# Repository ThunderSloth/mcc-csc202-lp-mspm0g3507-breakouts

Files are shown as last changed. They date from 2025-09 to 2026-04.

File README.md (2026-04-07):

# MCC CSC202 — LP-MSPM0G3507 Breakout Boards

KiCad project files and fabrication outputs for **breakout boards based on the TI MSPM0G3507 LaunchPad footprint** designed to fit dual- and triple-breadboard platforms (e.g., Jameco ValuePro) for use in Monroe Community College’s CSC-202 course.

---

## ℹ️  Hardware Documentation (MkDocs)

- **[Live Docs Site (renders + PDFs + iBOM + fabrication zips](https://thundersloth.github.io/mcc-csc202-lp-mspm0g3507-breakouts/)**  

---

## 📁 Boards

### **2-Term Breakout**
- [Docs Page](https://thundersloth.github.io/mcc-csc202-lp-mspm0g3507-breakouts/2-term/)
- [Download Gerbers (ZIP)](https://thundersloth.github.io/mcc-csc202-lp-mspm0g3507-breakouts/artifacts/2-term/fab/CSC202_LP_MSPM0G3507_2TERM_BREAKOUT_fab.zip)

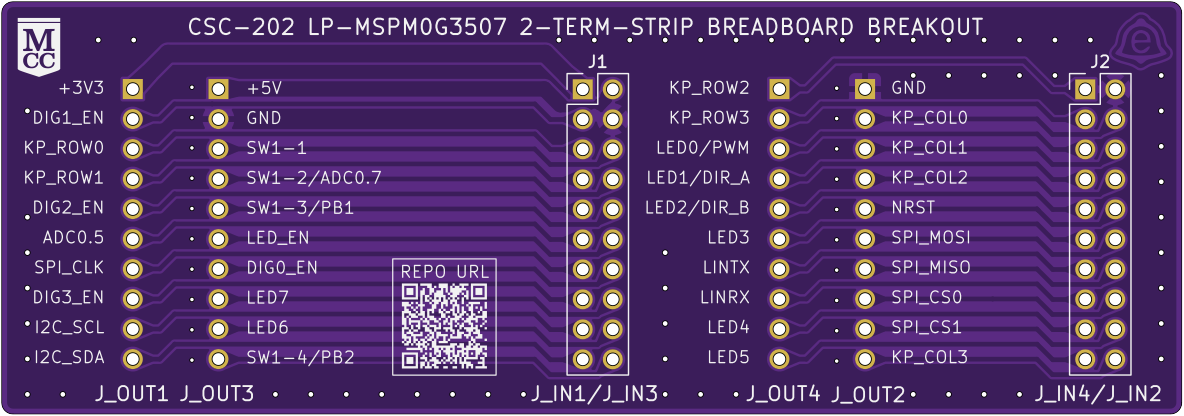
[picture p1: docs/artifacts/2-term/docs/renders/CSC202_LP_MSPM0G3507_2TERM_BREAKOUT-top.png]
2-Term Top Render


---

### **3-Term Breakout**
- [Docs Page](https://thundersloth.github.io/mcc-csc202-lp-mspm0g3507-breakouts/3-term/)
- [Download Gerbers (ZIP)](https://thundersloth.github.io/mcc-csc202-lp-mspm0g3507-breakouts/artifacts/3-term/fab/CSC202_LP_MSPM0G3507_3TERM_BREAKOUT_fab.zip)

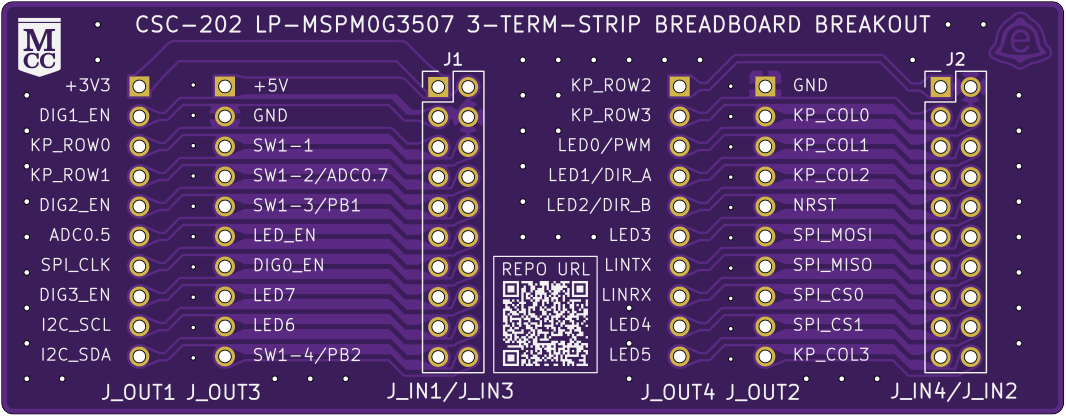
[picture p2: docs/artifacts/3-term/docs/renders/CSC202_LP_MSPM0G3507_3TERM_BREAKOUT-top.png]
3-Term Top Render


---

### **LED Display Module**
The CSC-202 LED Module is a visual output board featuring an 8-LED bar graph and a 4-digit seven-segment display. The LEDs and display segments can be driven either directly via GPIO (current sinking) or through an SPI shift register interface. A jumper shunt selects the control mode, allowing the module to demonstrate both parallel GPIO control and serial output expansion. The board is designed to plug directly into a standard breadboard for easy prototyping and lab use.
- [Docs Page](https://thundersloth.github.io/mcc-csc202-lp-mspm0g3507-breakouts/led-module/)
- [Download Gerbers (ZIP)](https://thundersloth.github.io/mcc-csc202-lp-mspm0g3507-breakouts/artifacts/led-module/fab/CSC202_LED_MODULE_fab.zip.zip)

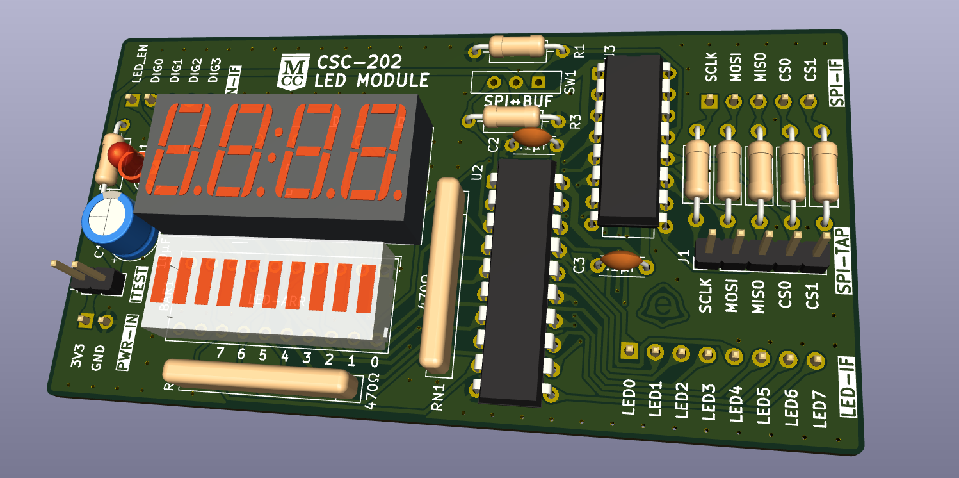
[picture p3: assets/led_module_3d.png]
LED Display Module 3D Render


---

### **DIP Switch / Pushbutton Module**
The CSC-202 DIP Switch / Pushbutton Module provides four digital input channels, each connected to both a DIP switch and a momentary pushbutton. This allows testing of both persistent and transient inputs on shared GPIO lines. An additional analog input is provided via an onboard potentiometer, which can be enabled or disconnected using a dedicated DIP switch. The module is designed for direct breadboard use and serves as a simple, reusable input interface for labs and debugging.

- [Docs Page](https://thundersloth.github.io/mcc-csc202-lp-mspm0g3507-breakouts/dipsw-module/)
- [Download Gerbers (ZIP)](https://thundersloth.github.io/mcc-csc202-lp-mspm0g3507-breakouts/artifacts/dipsw-module/fab/CSC202_DIPSW_fab.zip)

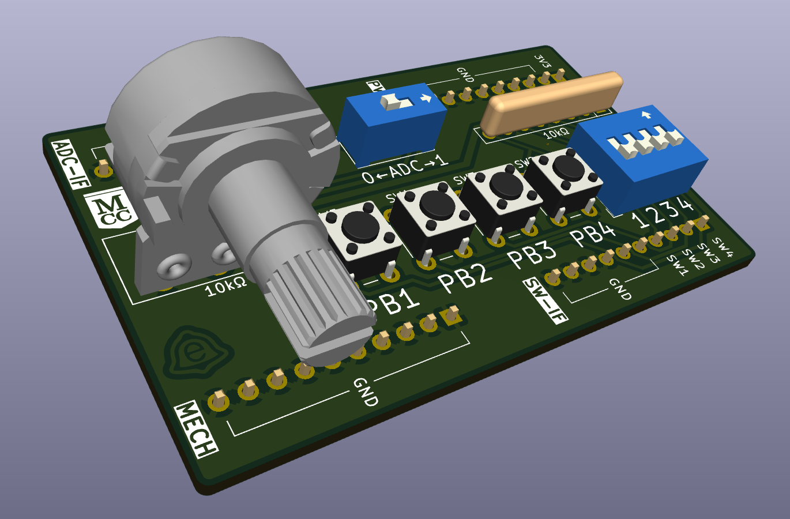
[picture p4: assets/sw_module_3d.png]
DIP Switch Module 3D Render


---

## 🛠 Repo Layout

- `hardware/pcb/kicad/` → KiCad source projects (per-board)
- `hardware/kibot/` → KiBot config
- `outputs/` → local generated artifacts (ignored/regen as needed)
- `docs/` + `docs/artifacts/` → MkDocs site + published artifacts

---

## 🔄 Generating outputs locally

If you want to regenerate all artifacts with KiBot + sync them into MkDocs:

```bash
make
```

---

## 📸 Fabricated Board Photos

<p align="center">
    <strong>3-Term Breakout</strong><br>
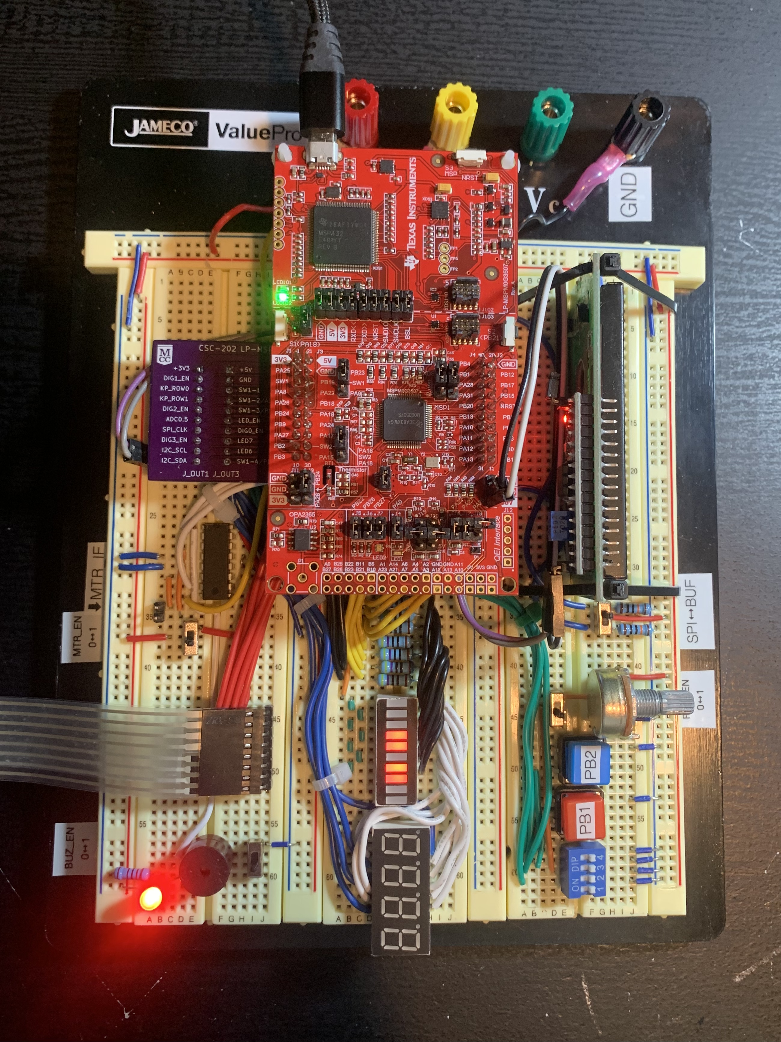
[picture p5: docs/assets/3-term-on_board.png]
3-Term breakout on breadboard
  
</p>

<p align="center">
  <strong>LED Display Module</strong><br>
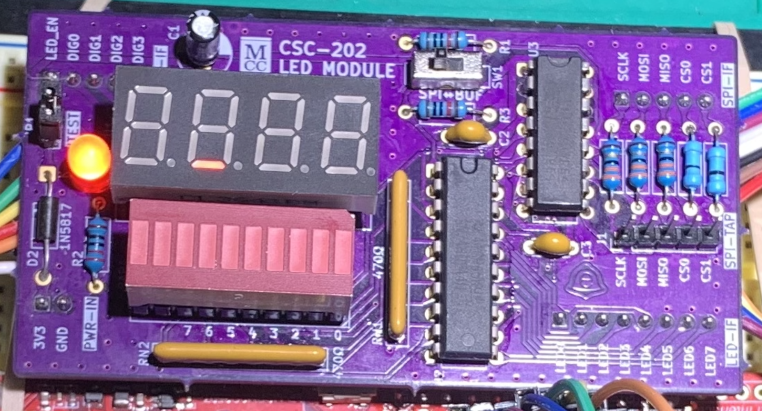
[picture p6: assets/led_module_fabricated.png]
Fabricated LED Module
  
</p>

---

## 📐 Example Breadboard Application

The diagram below shows an example application implemented on a 3-terminal breadboard.

<p align="center">
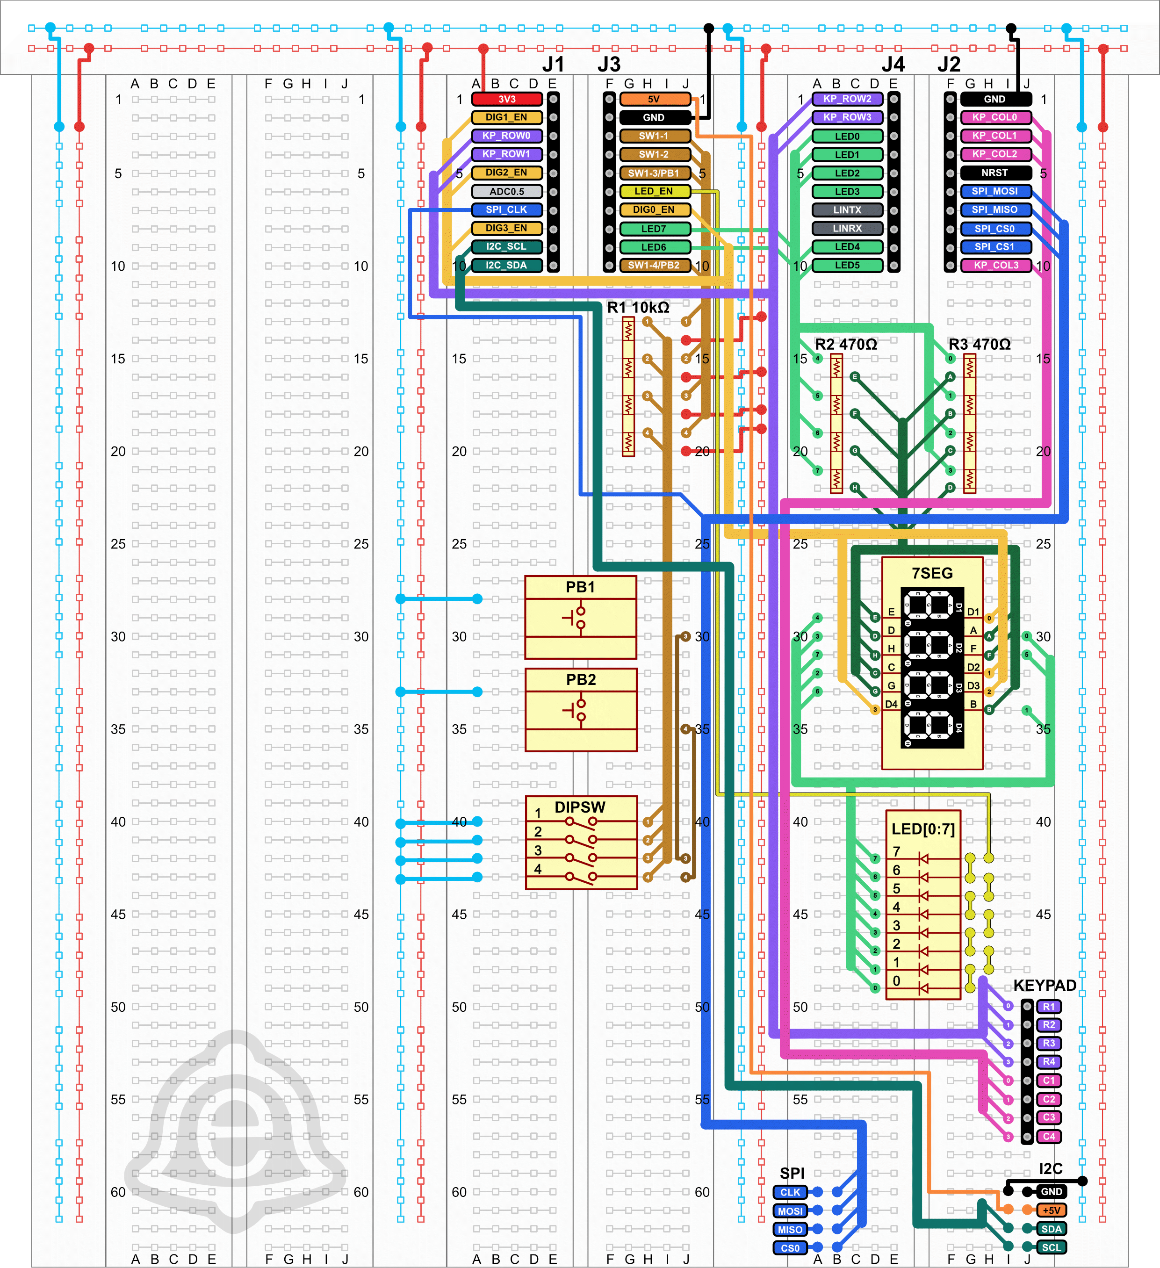
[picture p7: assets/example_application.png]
Example Application Breadboard Schematic
  
</p>

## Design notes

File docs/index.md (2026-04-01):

# CSC-202 LP-MSPM0G3507 Breakouts — Hardware Documentation

This site hosts the complete set of design, assembly, and fabrication artifacts generated from the KiCad projects via **KiBot**.

---

## ℹ️ Project
GitHub Repository: [ThunderSloth/mcc-csc202-lp-mspm0g3507-breakouts](https://github.com/ThunderSloth/mcc-csc202-lp-mspm0g3507-breakouts)

---

## 📁 Boards
### 2-Term Breakout

2-Term Breakout top render

➡️ [Open page](2-term.md)

---

### 3-Term Breakout

3-Term Breakout top render

➡️ [Open page](3-term.md)

---

### LED Display Module

<div class="img-row">
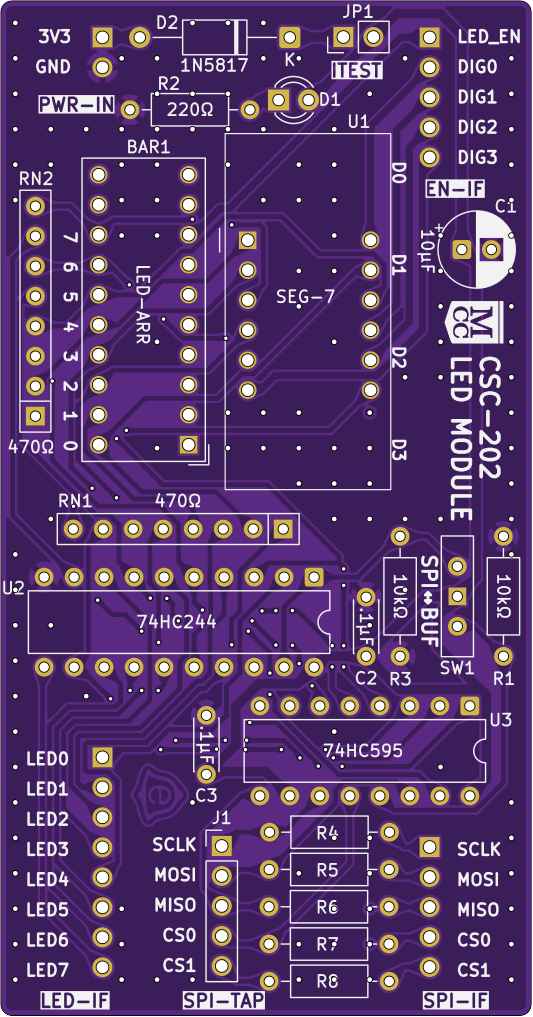
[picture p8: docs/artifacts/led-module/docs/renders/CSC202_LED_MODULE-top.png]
LED Display Module top render
    
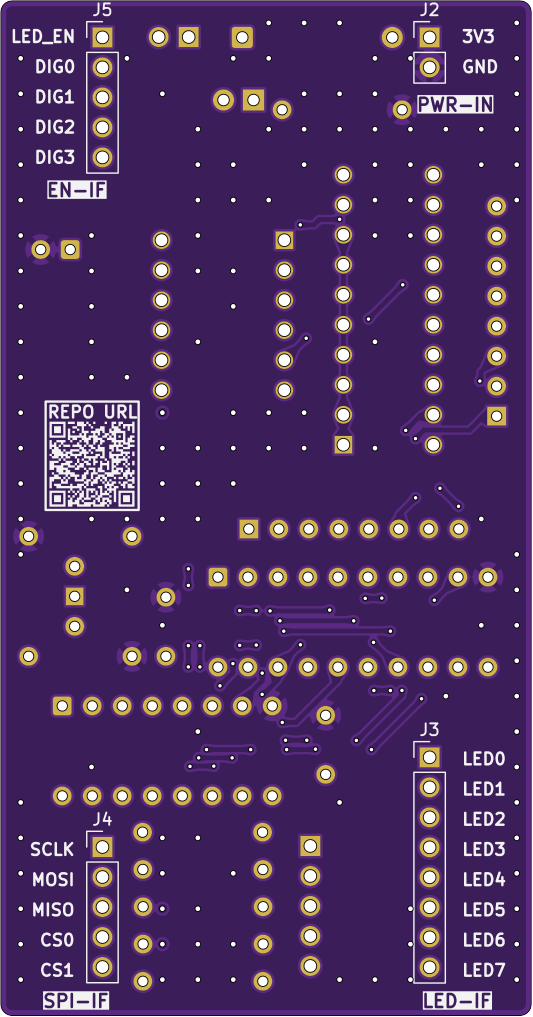
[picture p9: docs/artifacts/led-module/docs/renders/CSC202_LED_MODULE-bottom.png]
LED Display Module bottom render
    
</div>

➡️ [Open page](led-module.md)

---

### DIP Switch Module

<div class="img-row">
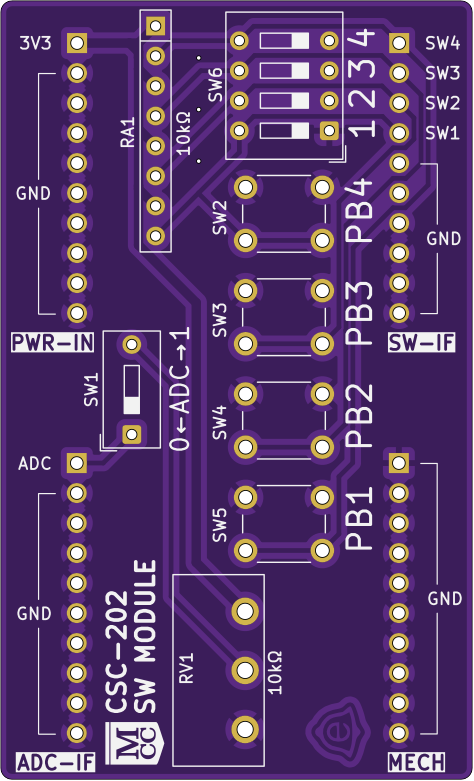
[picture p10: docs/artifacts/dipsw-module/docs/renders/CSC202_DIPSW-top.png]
DIP Switch Module top render
    
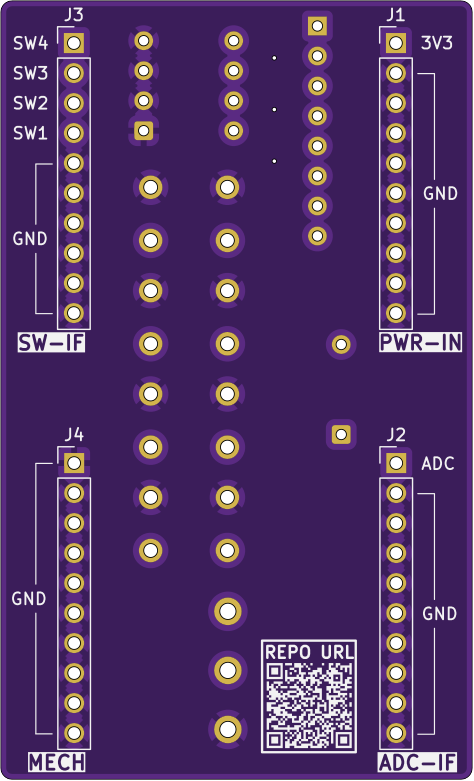
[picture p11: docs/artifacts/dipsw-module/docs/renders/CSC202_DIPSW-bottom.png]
DIP Switch Module bottom render
    
</div>

➡️ [Open page](dipsw-module.md)

---

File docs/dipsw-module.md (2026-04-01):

# DIP Switch Module

This page hosts the complete set of design, assembly, and fabrication artifacts generated from the KiCad project via **KiBot**.

---

## 📐 Design

- **Schematic (PDF)** [[view]](artifacts/dipsw-module/docs/schematic/CSC202_DIPSW-schematic.pdf)
- **PCB Render — Top (2D)** [[view]](artifacts/dipsw-module/docs/renders/CSC202_DIPSW-top.png)
- **PCB Render — Bottom (2D)** [[view]](artifacts/dipsw-module/docs/renders/CSC202_DIPSW-bottom.png)

---

## 🔧 Assembly

- **Interactive BOM (iBOM)** [[view]](artifacts/dipsw-module/docs/ibom/CSC202_DIPSW-ibom.html)
- **Bill of Materials (CSV)** [[view]](artifacts/dipsw-module/assembly/CSC202_DIPSW-bom.csv.html) [[download]](artifacts/dipsw-module/assembly/CSC202_DIPSW-bom.csv)
- **Assembly Drawing — Top (PDF)** [[view]](artifacts/dipsw-module/docs/assembly/CSC202_DIPSW-assembly-top.pdf)
- **Assembly Drawing — Bottom (PDF)** [[view]](artifacts/dipsw-module/docs/assembly/CSC202_DIPSW-assembly-bottom.pdf)

---

## ⚙️ Fabrication

- **Fabrication Drawing (PDF)** [[view]](artifacts/dipsw-module/docs/fab/CSC202_DIPSW-fab-drawing.pdf)
- **Gerbers & Drill Files (ZIP)** [[download]](artifacts/dipsw-module/fab/CSC202_DIPSW_fab.zip)

---

## 🧊 Mechanical

- **3D STEP Model** [[download]](artifacts/dipsw-module/mcad/CSC202_DIPSW-3D.step)

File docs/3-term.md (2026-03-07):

# 3-Term Breakout

This page hosts the complete set of design, assembly, and fabrication artifacts generated from the KiCad project via **KiBot**.

---

## 📐 Design

- **Schematic (PDF)** [[view]](artifacts/3-term/docs/schematic/CSC202_LP_MSPM0G3507_3TERM_BREAKOUT-schematic.pdf)
- **PCB Render — Top (2D)** [[view]](artifacts/3-term/docs/renders/CSC202_LP_MSPM0G3507_3TERM_BREAKOUT-top.png)
- **PCB Render — Bottom (2D)** [[view]](artifacts/3-term/docs/renders/CSC202_LP_MSPM0G3507_3TERM_BREAKOUT-bottom.png)

---

## 🔧 Assembly

- **Interactive BOM (iBOM)** [[view]](artifacts/3-term/docs/ibom/CSC202_LP_MSPM0G3507_3TERM_BREAKOUT-ibom.html)
- **Bill of Materials (CSV)** [[view]](artifacts/3-term/assembly/CSC202_LP_MSPM0G3507_3TERM_BREAKOUT-bom.csv.html) [[download]](artifacts/3-term/assembly/CSC202_LP_MSPM0G3507_3TERM_BREAKOUT-bom.csv)
- **Assembly Drawing — Top (PDF)** [[view]](artifacts/3-term/docs/assembly/CSC202_LP_MSPM0G3507_3TERM_BREAKOUT-assembly-top.pdf)
- **Assembly Drawing — Bottom (PDF)** [[view]](artifacts/3-term/docs/assembly/CSC202_LP_MSPM0G3507_3TERM_BREAKOUT-assembly-bottom.pdf)

---

## ⚙️ Fabrication

- **Fabrication Drawing (PDF)** [[view]](artifacts/3-term/docs/fab/CSC202_LP_MSPM0G3507_3TERM_BREAKOUT-fab-drawing.pdf)
- **Gerbers & Drill Files (ZIP)** [[download]](artifacts/3-term/fab/CSC202_LP_MSPM0G3507_3TERM_BREAKOUT_fab.zip)

---

## 🧊 Mechanical

- **3D STEP Model** [[download]](artifacts/3-term/mcad/CSC202_LP_MSPM0G3507_3TERM_BREAKOUT-3D.step)

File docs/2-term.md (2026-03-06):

# 2-Term Breakout

This page hosts the complete set of design, assembly, and fabrication artifacts generated from the KiCad project via **KiBot**.

---

## 📐 Design

- **Schematic (PDF)** [[view]](artifacts/2-term/docs/schematic/CSC202_LP_MSPM0G3507_2TERM_BREAKOUT-schematic.pdf)
- **PCB Render — Top (2D)** [[view]](artifacts/2-term/docs/renders/CSC202_LP_MSPM0G3507_2TERM_BREAKOUT-top.png)
- **PCB Render — Bottom (2D)** [[view]](artifacts/2-term/docs/renders/CSC202_LP_MSPM0G3507_2TERM_BREAKOUT-bottom.png)

---

## 🔧 Assembly

- **Interactive BOM (iBOM)** [[view]](artifacts/2-term/docs/ibom/CSC202_LP_MSPM0G3507_2TERM_BREAKOUT-ibom.html)
- **Bill of Materials (CSV)** [[view]](artifacts/2-term/assembly/CSC202_LP_MSPM0G3507_2TERM_BREAKOUT-bom.csv.html) [[download]](artifacts/2-term/assembly/CSC202_LP_MSPM0G3507_2TERM_BREAKOUT-bom.csv)
- **Assembly Drawing — Top (PDF)** [[view]](artifacts/2-term/docs/assembly/CSC202_LP_MSPM0G3507_2TERM_BREAKOUT-assembly-top.pdf)
- **Assembly Drawing — Bottom (PDF)** [[view]](artifacts/2-term/docs/assembly/CSC202_LP_MSPM0G3507_2TERM_BREAKOUT-assembly-bottom.pdf)

---

## ⚙️ Fabrication

- **Fabrication Drawing (PDF)** [[view]](artifacts/2-term/docs/fab/CSC202_LP_MSPM0G3507_2TERM_BREAKOUT-fab-drawing.pdf)
- **Gerbers & Drill Files (ZIP)** [[download]](artifacts/2-term/fab/CSC202_LP_MSPM0G3507_2TERM_BREAKOUT_fab.zip)

---

## 🧊 Mechanical

- **3D STEP Model** [[download]](artifacts/2-term/mcad/CSC202_LP_MSPM0G3507_2TERM_BREAKOUT-3D.step)

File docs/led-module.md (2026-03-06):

# LED Display Module

This page hosts the complete set of design, assembly, and fabrication artifacts generated from the KiCad project via **KiBot**.

---

## 📐 Design

- **Schematic (PDF)** [[view]](artifacts/led-module/docs/schematic/CSC202_LED_MODULE-schematic.pdf)
- **PCB Render — Top (2D)** [[view]](artifacts/led-module/docs/renders/CSC202_LED_MODULE-top.png)
- **PCB Render — Bottom (2D)** [[view]](artifacts/led-module/docs/renders/CSC202_LED_MODULE-bottom.png)

---

## 🔧 Assembly

- **Interactive BOM (iBOM)** [[view]](artifacts/led-module/docs/ibom/CSC202_LED_MODULE-ibom.html)
- **Bill of Materials (CSV)** [[view]](artifacts/led-module/assembly/CSC202_LED_MODULE-bom.csv.html) [[download]](artifacts/led-module/assembly/CSC202_LED_MODULE-bom.csv)
- **Assembly Drawing — Top (PDF)** [[view]](artifacts/led-module/docs/assembly/CSC202_LED_MODULE-assembly-top.pdf)
- **Assembly Drawing — Bottom (PDF)** [[view]](artifacts/led-module/docs/assembly/CSC202_LED_MODULE-assembly-bottom.pdf)

---

## ⚙️ Fabrication

- **Fabrication Drawing (PDF)** [[view]](artifacts/led-module/docs/fab/CSC202_LED_MODULE-fab-drawing.pdf)
- **Gerbers & Drill Files (ZIP)** [[download]](artifacts/led-module/fab/CSC202_LED_MODULE_fab.zip)

---

## 🧊 Mechanical

- **3D STEP Model** [[download]](artifacts/led-module/mcad/CSC202_LED_MODULE-3D.step)

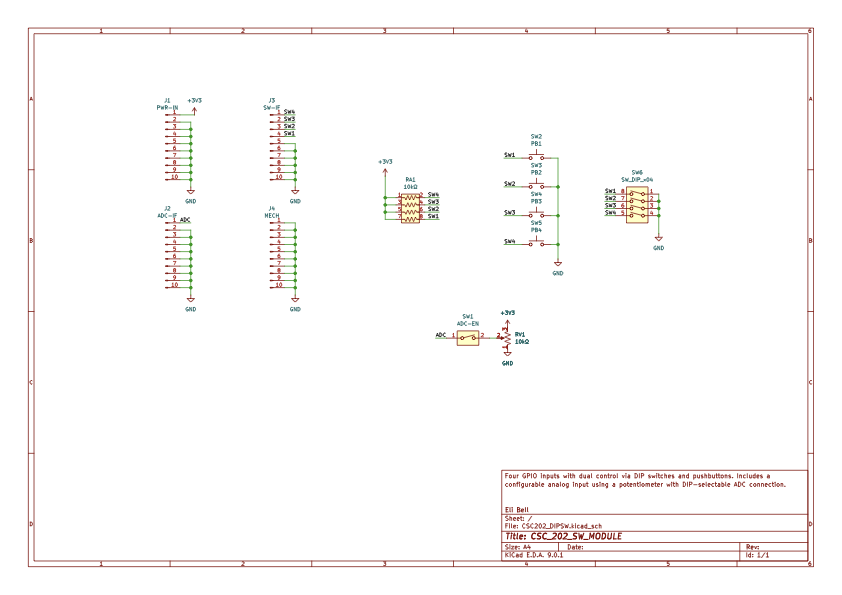
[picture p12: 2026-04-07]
docs/artifacts/dipsw-module/previews/schematic.png

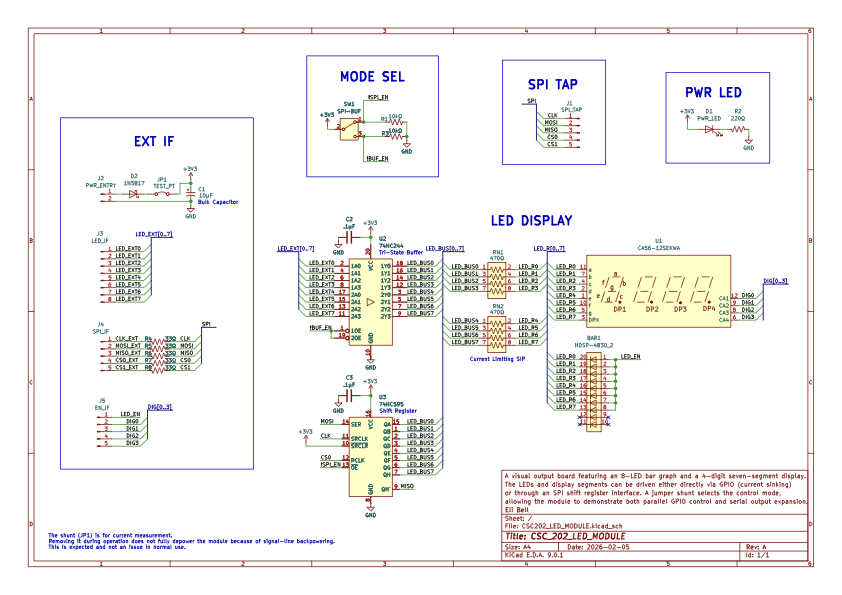
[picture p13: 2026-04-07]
docs/artifacts/led-module/previews/schematic.png

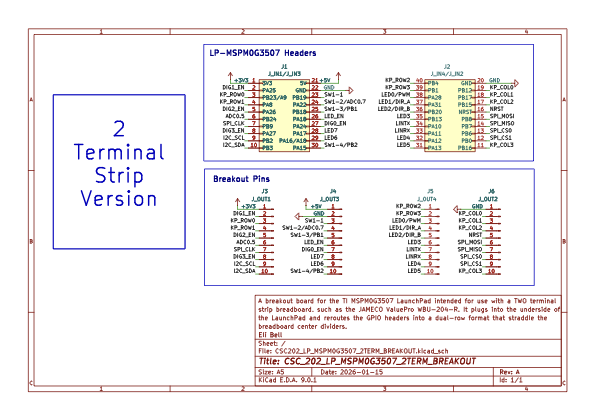
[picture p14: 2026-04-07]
docs/artifacts/2-term/previews/schematic.png

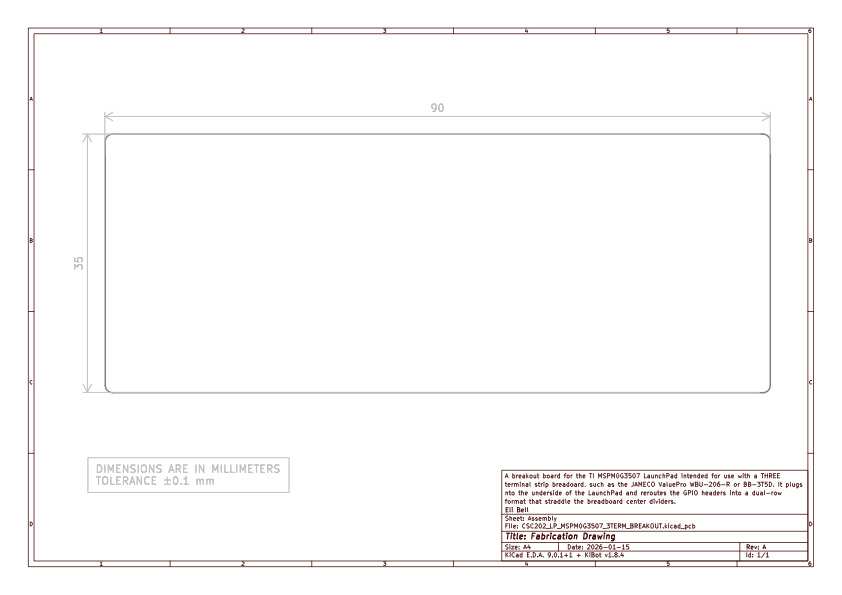
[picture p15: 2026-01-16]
docs/artifacts/3-term/previews/fab-drawing.png

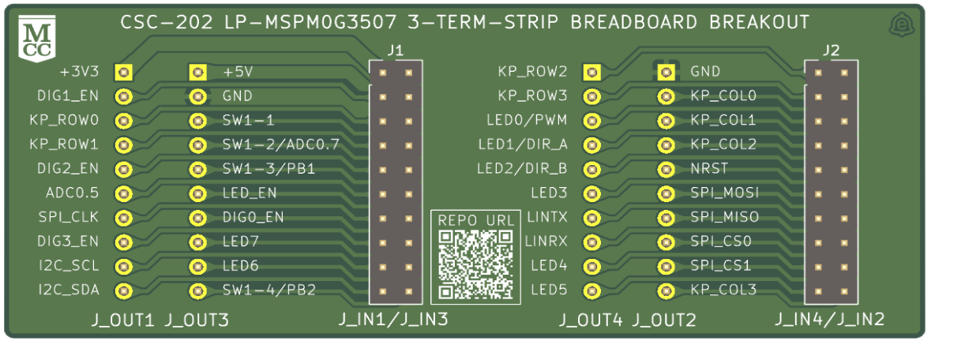
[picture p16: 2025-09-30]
docs/assets/CSC202_LP_MSPM0G3507_3TERM_BREAKOUT.png

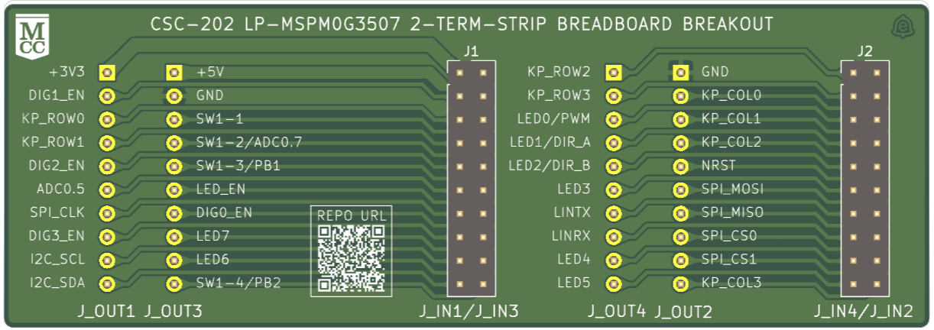
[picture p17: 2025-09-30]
docs/assets/CSC202_LP_MSPM0G3507_2TERM_BREAKOUT.png

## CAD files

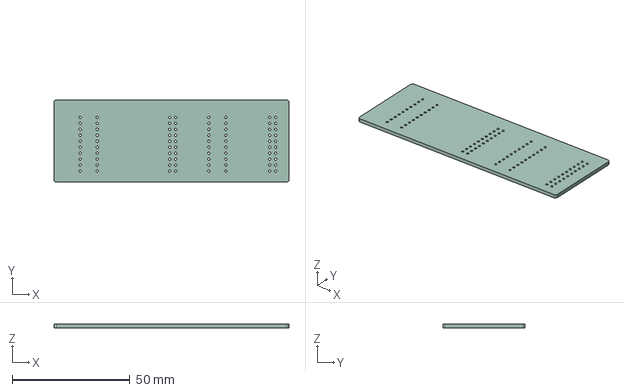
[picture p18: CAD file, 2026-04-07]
docs/artifacts/2-term/mcad/CSC202_LP_MSPM0G3507_2TERM_BREAKOUT-3D.step
100.0 x 35.0 x 1.51 mm

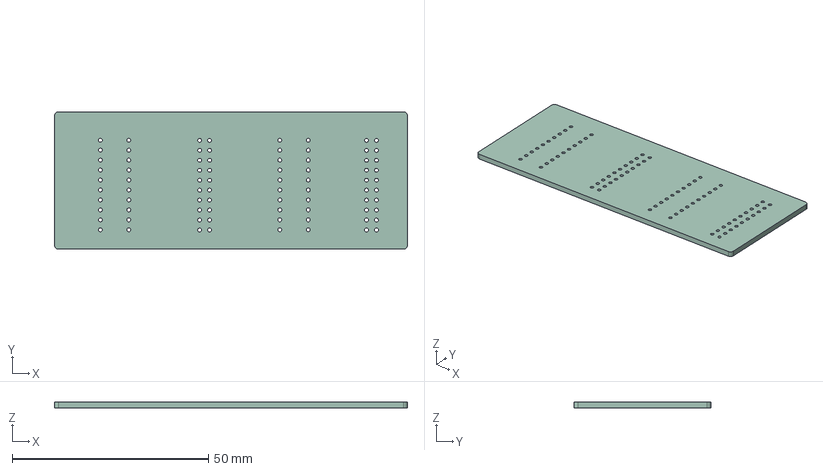
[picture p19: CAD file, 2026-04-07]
docs/artifacts/3-term/mcad/CSC202_LP_MSPM0G3507_3TERM_BREAKOUT-3D.step
90.0 x 35.0 x 1.51 mm

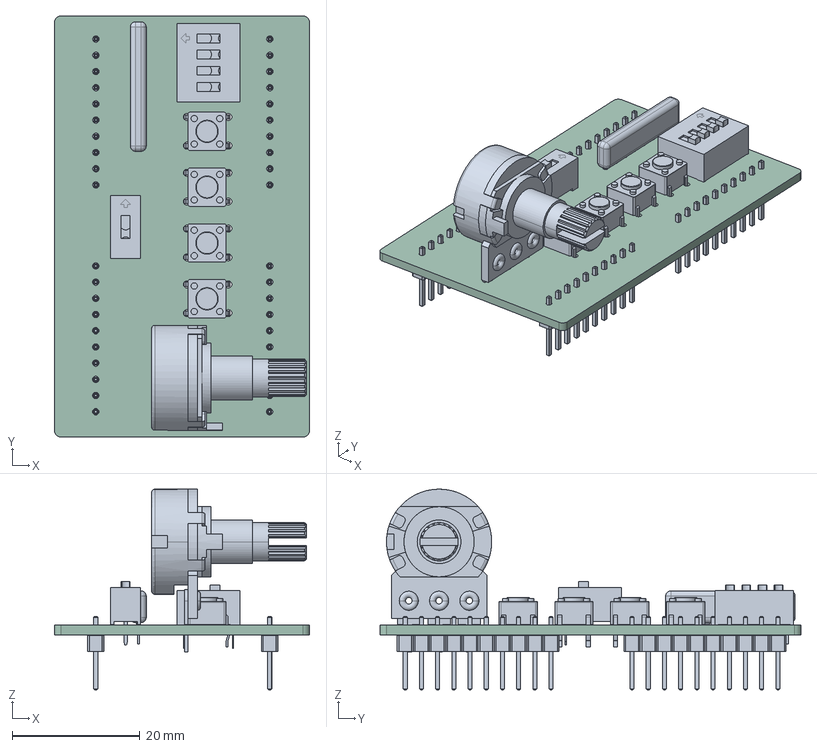
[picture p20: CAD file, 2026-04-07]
docs/artifacts/dipsw-module/mcad/CSC202_DIPSW-3D.step
40.0 x 66.0 x 31.5 mm
SW_PUSH_6mm x 4
Potentiometer
SW_DIP_SPSTx01_Slide_9.78x4.72mm_W7.62mm_P2.54mm
R_Array_SIP8
SW_DIP_SPSTx04_Slide_9.78x12.34mm_W7.62mm_P2.54mm
PinHeader_1x10_P2.54mm_Vertical x 4
kibot_9wbtitek_PCB

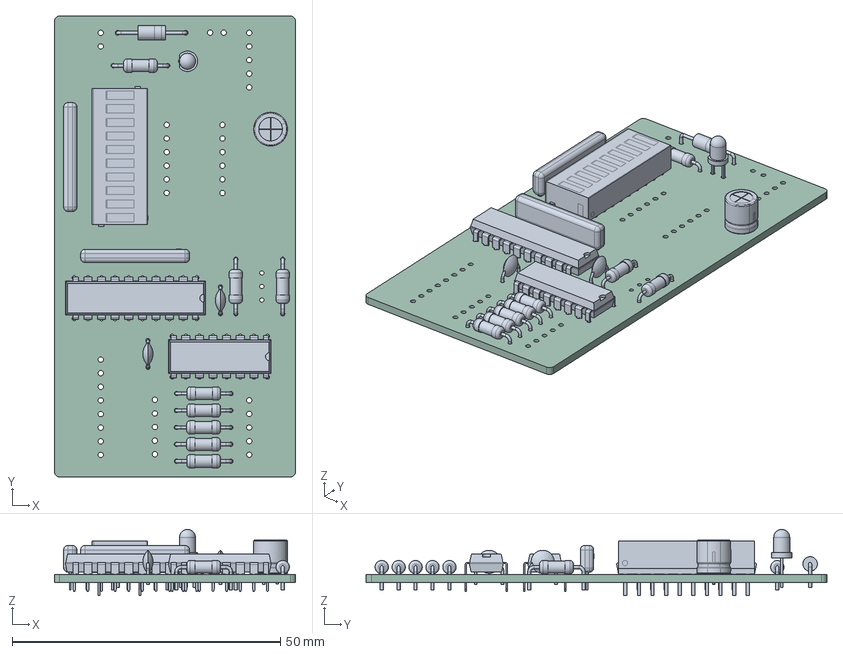
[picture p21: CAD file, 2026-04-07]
docs/artifacts/led-module/mcad/CSC202_LED_MODULE-3D.step
45.0 x 86.0 x 12.4 mm
R_Axial_DIN0207_L6.3mm_D2.5mm_P10.16mm_Horizontal_2_2_1
R_Axial_DIN0207_L6.3mm_D2.5mm_P10.16mm_Horizontal_3_3_0 x 5
R_Array_SIP8 x 2
C_Disc_D4.3mm_W1.9mm_P5.00mm x 2
DIP-16_W7.62mm
DIP-20_W7.62mm
R_Axial_DIN0207_L6.3mm_D2.5mm_P10.16mm_Horizontal_1_0_3 x 2
HDSP-4830
D_A-405_P12.70mm_Horizontal
CP_Radial_D6.3mm_P2.50mm
LED_D3.0mm
kibot_85yduw67_PCB

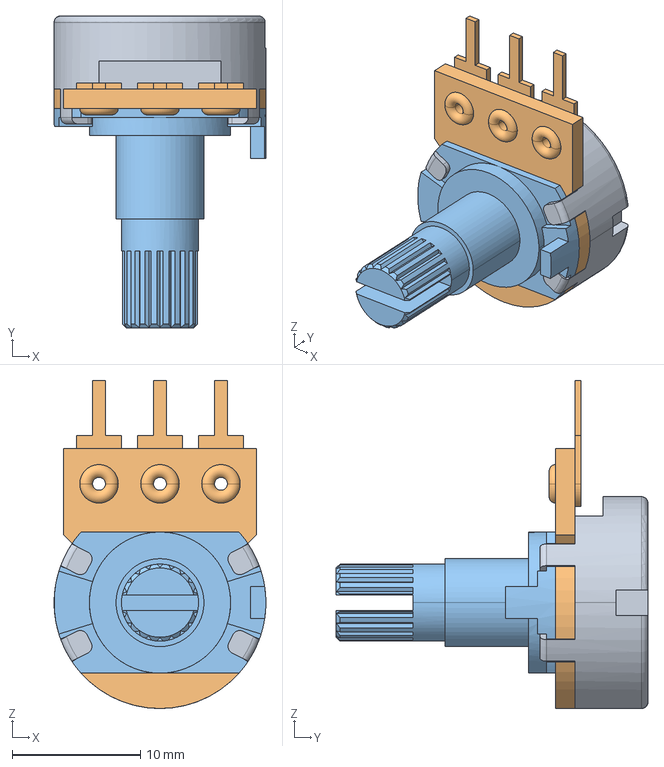
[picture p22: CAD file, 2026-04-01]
hardware/pcb/kicad/dipsw-module/CSC202_DIPSW/Potentiometer.stp
16.5 x 24.3 x 25.6 mm

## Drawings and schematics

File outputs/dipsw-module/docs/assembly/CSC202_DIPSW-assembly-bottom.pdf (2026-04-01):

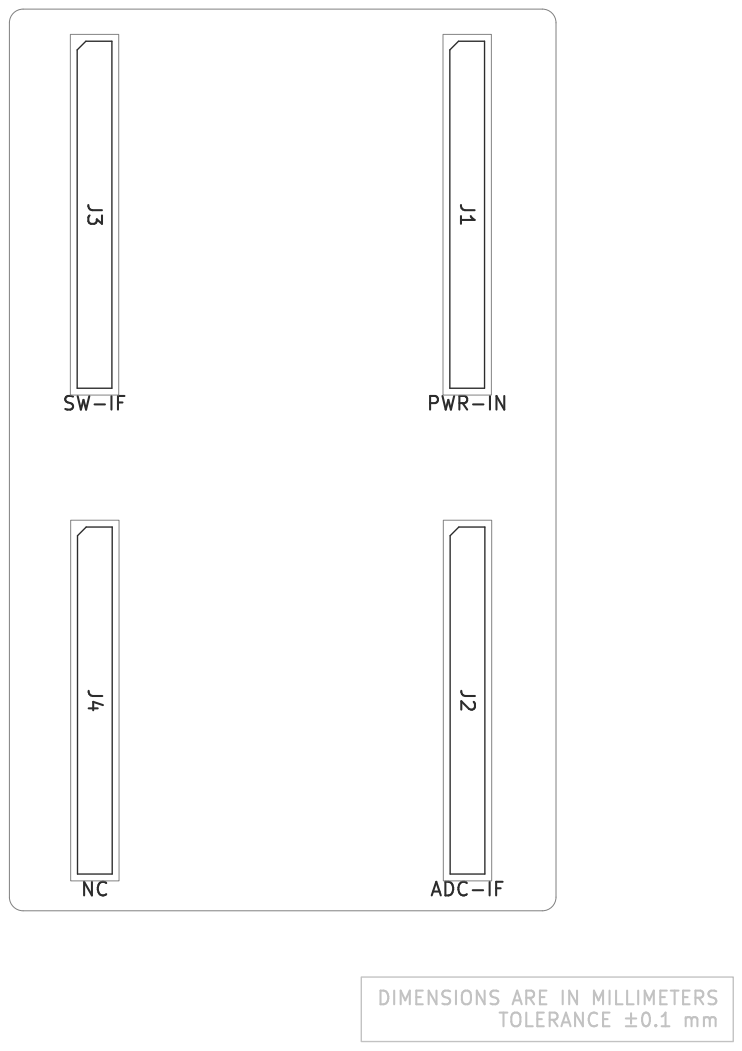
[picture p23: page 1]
Four GPIO inputs with dual control via; DIP switches and; pushbuttons.; Includes a; configurable analog input using a; potentiometer with; DIP-selectable ADC connection.; Eli; Bell; Size: A4; Rev:; KiCad; E.D.A. 9.0.1+1 + KiBot v1.8.4; Date: 2026-04-01_01-18-41; TOLERANCE ±0.1 mm; DIMENSIONS ARE; MILLIMETERS J2; ADC-IF; PWR-IN

Sheet: Assembly
File: CSC202_DIPSW.kicad_pcb
Title: Assembly Drawing (Bottom)

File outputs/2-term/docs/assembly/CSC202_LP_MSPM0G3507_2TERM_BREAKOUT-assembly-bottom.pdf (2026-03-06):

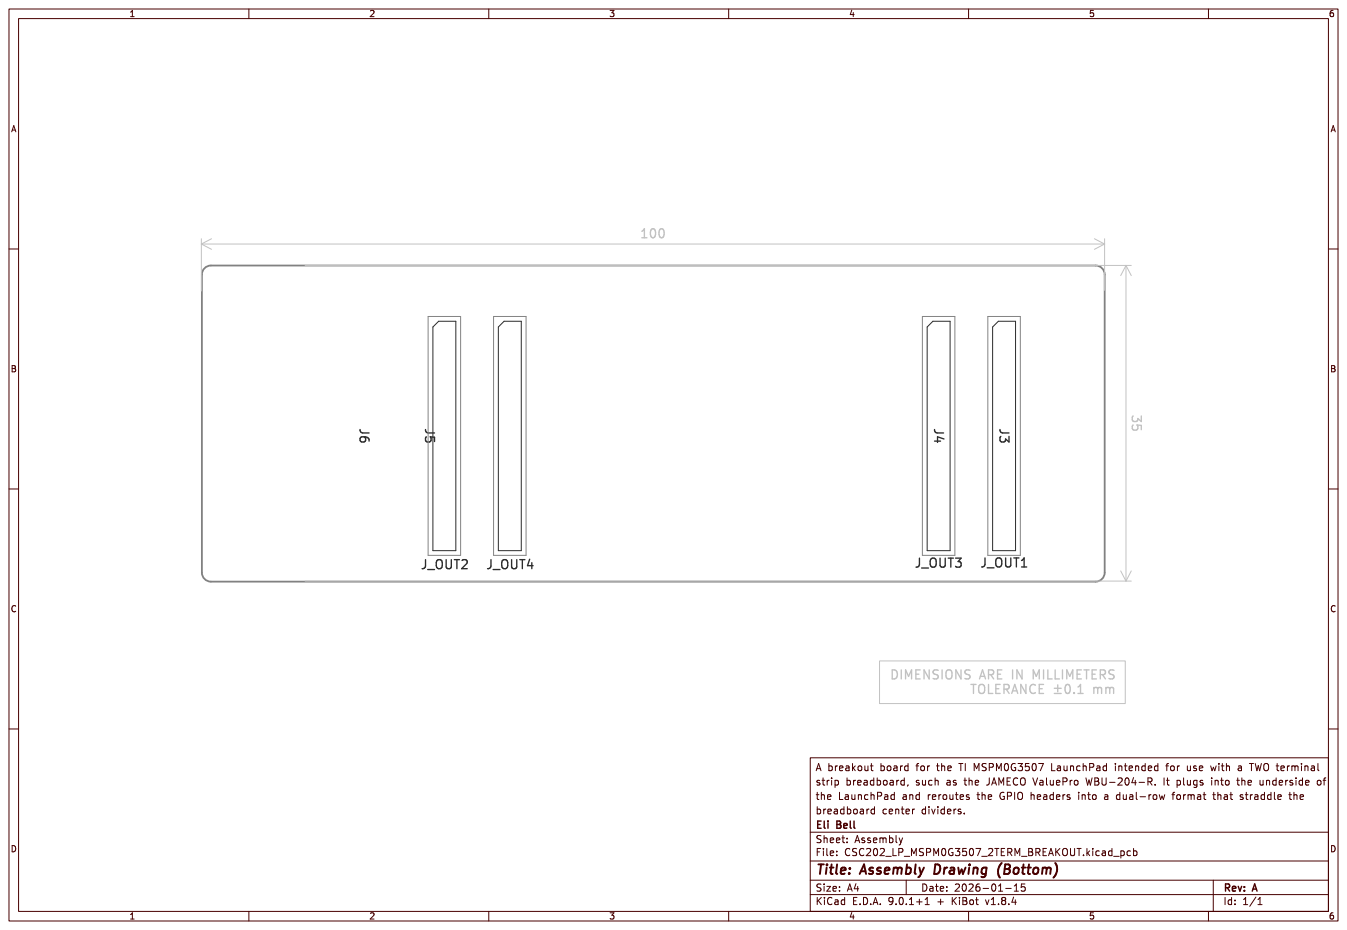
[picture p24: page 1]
A breakout board; for the TI; MSPM0G3507 LaunchPad intended; for use with a TWO terminal; strip; breadboard, such as the JAMECO ValuePro WBU-204-R. It plugs into the; underside; the; LaunchPad; and; reroutes the GPIO headers into a dual-row format that straddle the; breadboard; center dividers.; Eli; Bell; Size: A4; Rev: A; KiCad; E.D.A. 9.0.1+1 + KiBot v1.8.4; Date: 2026-01-15; TOLERANCE; DIMENSIONS ARE; MILLIMETERS; J_OUT4; J_OUT1; J_OUT2; J_OUT3

Sheet: Assembly
File: CSC202_LP_MSPM0G3507_2TERM_BREAKOUT.kicad_pcb
Title: Assembly Drawing (Bottom)

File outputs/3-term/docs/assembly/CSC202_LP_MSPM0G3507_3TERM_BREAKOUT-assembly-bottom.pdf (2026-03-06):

90

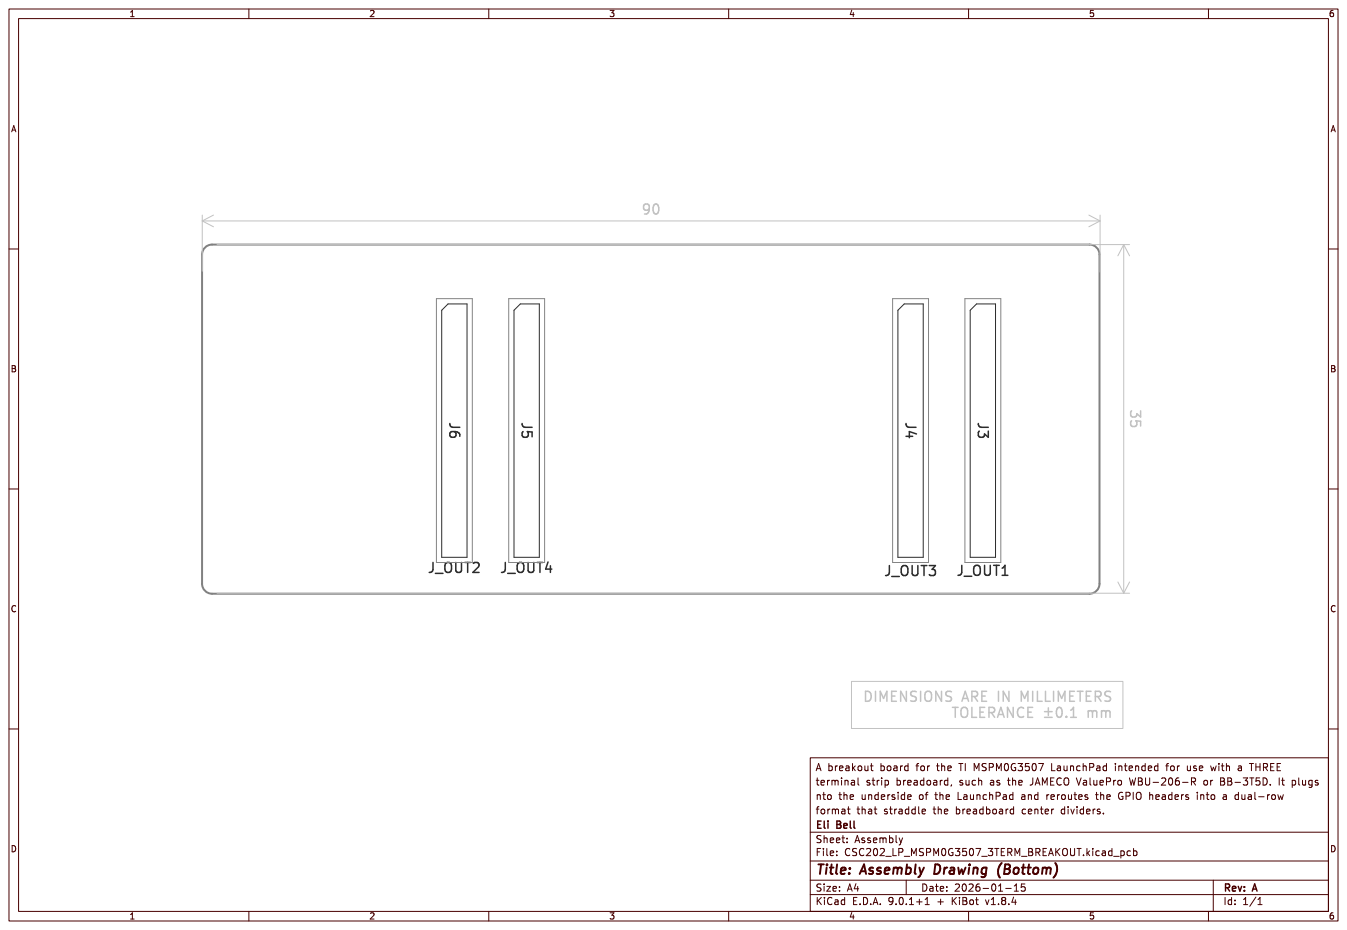
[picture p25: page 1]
A breakout board; for the TI; MSPM0G3507 LaunchPad intended; for use with a THREE; terminal strip; breadoard, such as; the JAMECO ValuePro WBU-206-R or BB-3T5D.; It plugs; nto the underside of the; LaunchPad; and; reroutes the GPIO headers into a dual-row; format that straddle; the; breadboard center; dividers.; Eli; Bell; Size: A4; Rev: A; KiCad; E.D.A. 9.0.1+1 + KiBot v1.8.4; Date: 2026-01-15; TOLERANCE; DIMENSIONS ARE; MILLIMETERS; J_OUT4; J_OUT1; J_OUT2; J_OUT3

Sheet: Assembly
File: CSC202_LP_MSPM0G3507_3TERM_BREAKOUT.kicad_pcb
Title: Assembly Drawing (Bottom)

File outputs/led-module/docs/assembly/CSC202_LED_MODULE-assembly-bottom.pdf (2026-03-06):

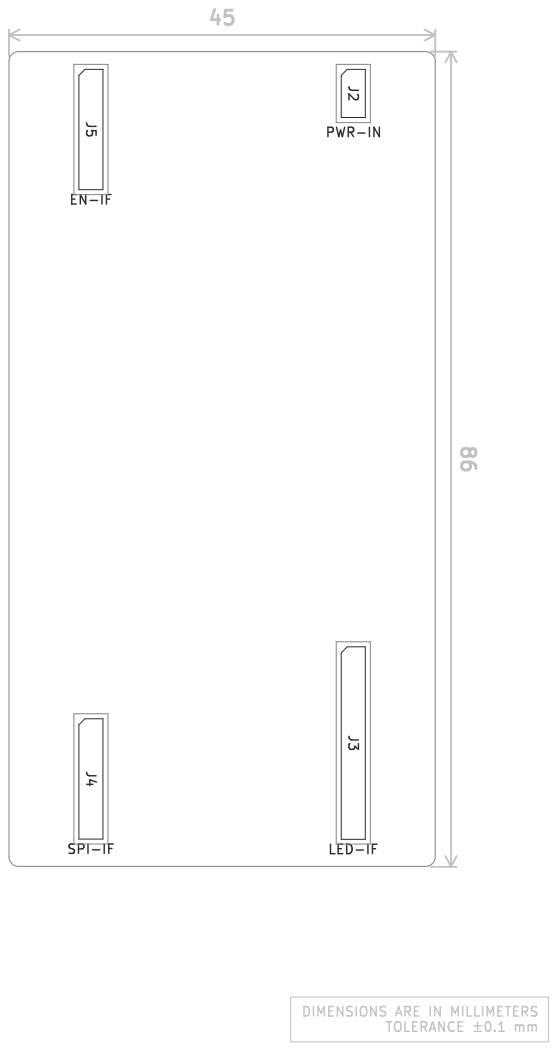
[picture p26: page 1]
A visual output; board featuring an 8-LED bar graph and; a 4-digit seven-segment display.; The LEDs and; display segments can be driven either directly via GPIO (current sinking); or through an SPI; shift register interface. A jumper; shunt selects the control; mode,; allowing the module to demonstrate both; parallel GPIO control and serial output expansion.; Eli; Bell; Size: A4; Rev: A; KiCad; E.D.A. 9.0.1+1 + KiBot v1.8.4; Date: 2026-01-15; TOLERANCE ±0.1 mm; SPI-IF; LED-IF; PWR-IN

DIMENSIONS ARE IN MILLIMETERS

Sheet: Assembly
File: CSC202_LED_MODULE.kicad_pcb
Title: Assembly Drawing (Bottom)

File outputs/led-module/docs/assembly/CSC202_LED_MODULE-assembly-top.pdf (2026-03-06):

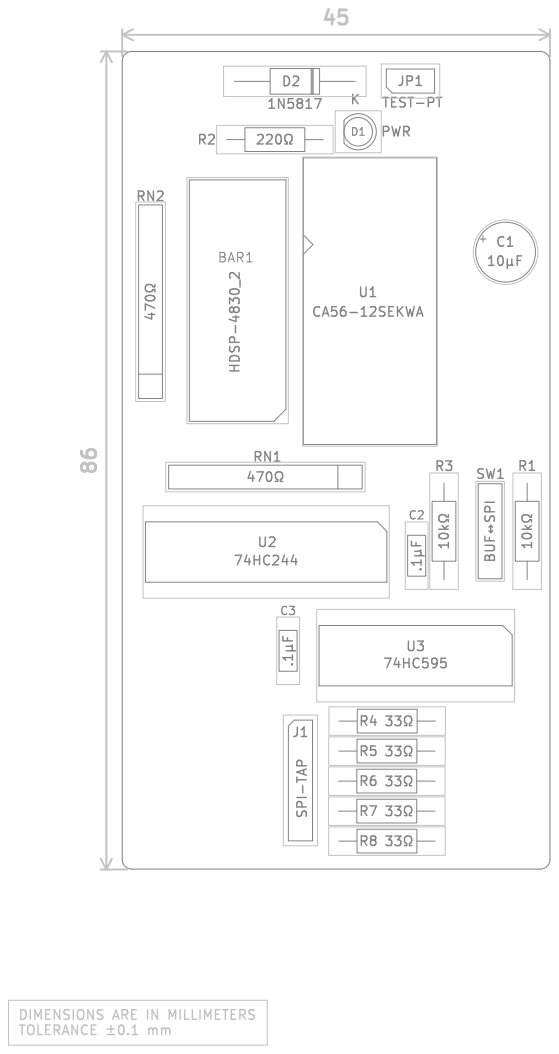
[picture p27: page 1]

DIMENSIONS ARE IN MILLIMETERS
TOLERANCE ±0.1 mm

Sheet: Assembly
File: CSC202_LED_MODULE.kicad_pcb
Title: Assembly Drawing (Top)

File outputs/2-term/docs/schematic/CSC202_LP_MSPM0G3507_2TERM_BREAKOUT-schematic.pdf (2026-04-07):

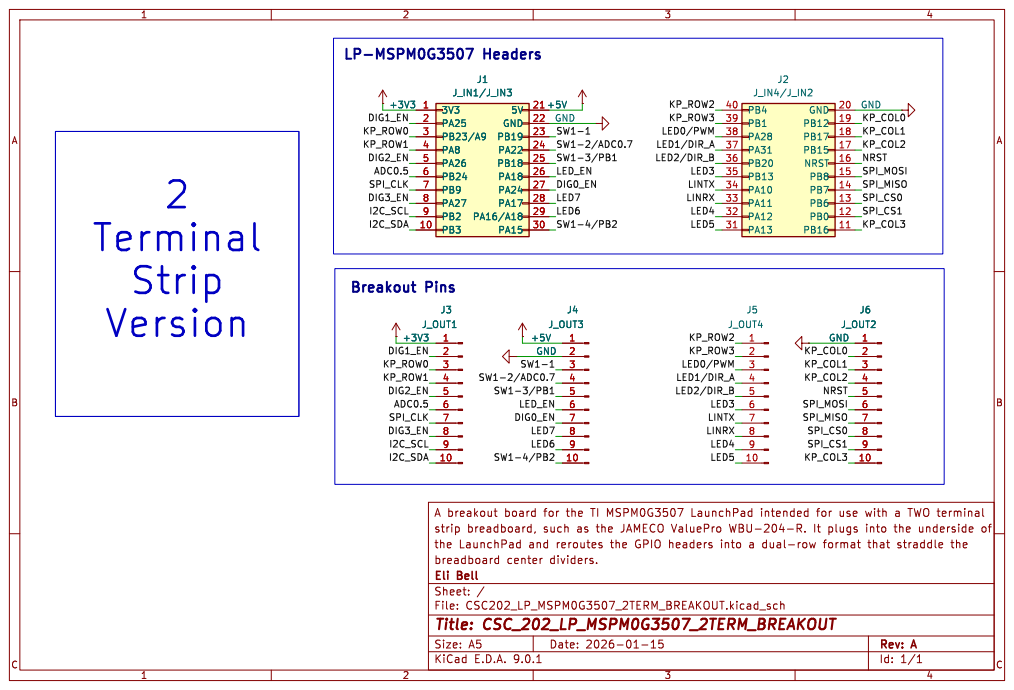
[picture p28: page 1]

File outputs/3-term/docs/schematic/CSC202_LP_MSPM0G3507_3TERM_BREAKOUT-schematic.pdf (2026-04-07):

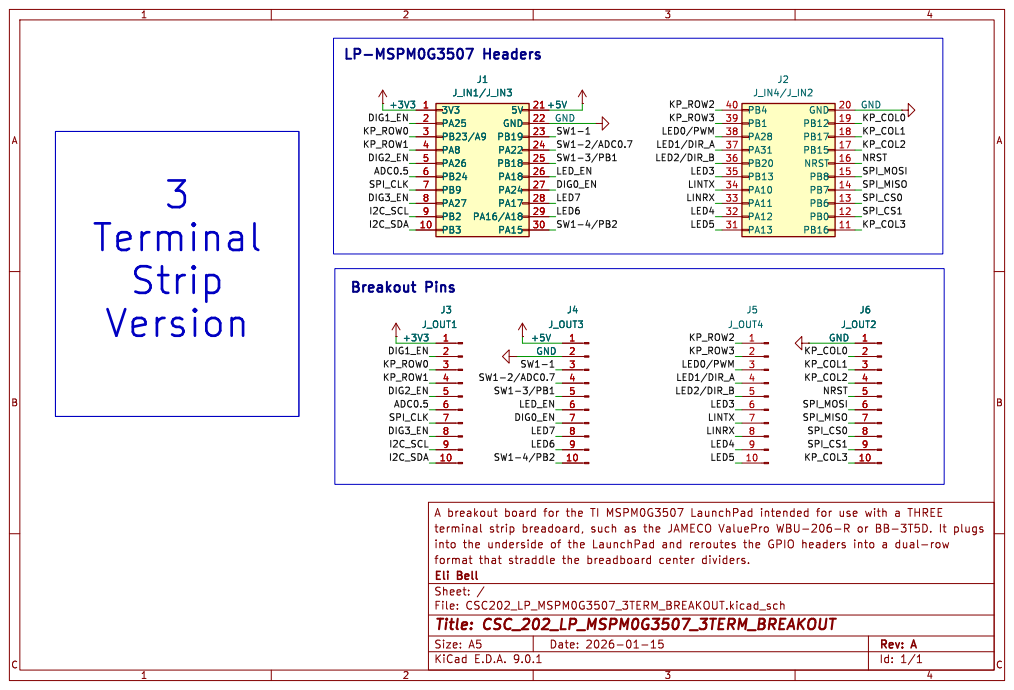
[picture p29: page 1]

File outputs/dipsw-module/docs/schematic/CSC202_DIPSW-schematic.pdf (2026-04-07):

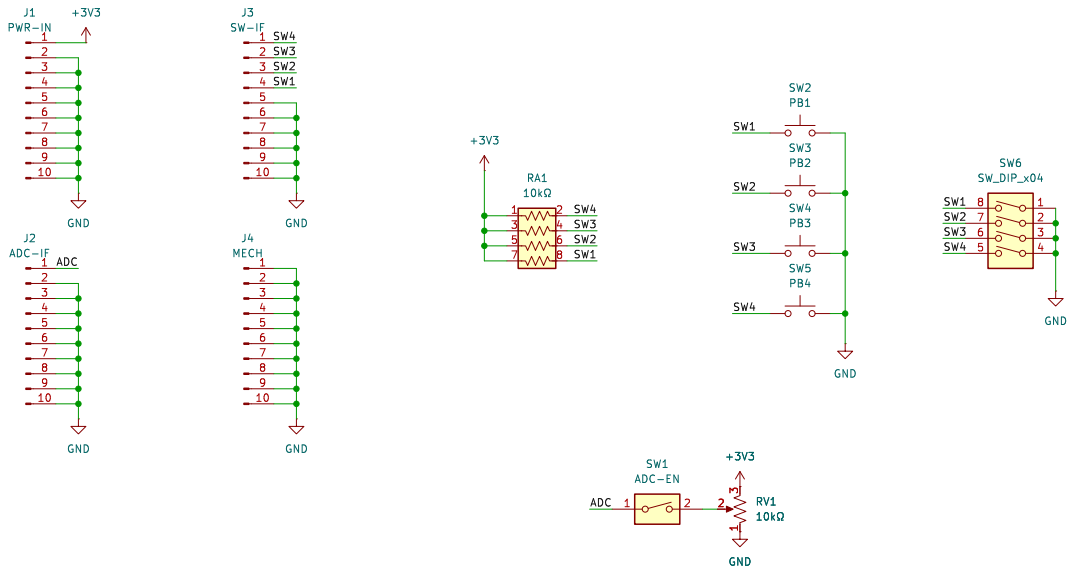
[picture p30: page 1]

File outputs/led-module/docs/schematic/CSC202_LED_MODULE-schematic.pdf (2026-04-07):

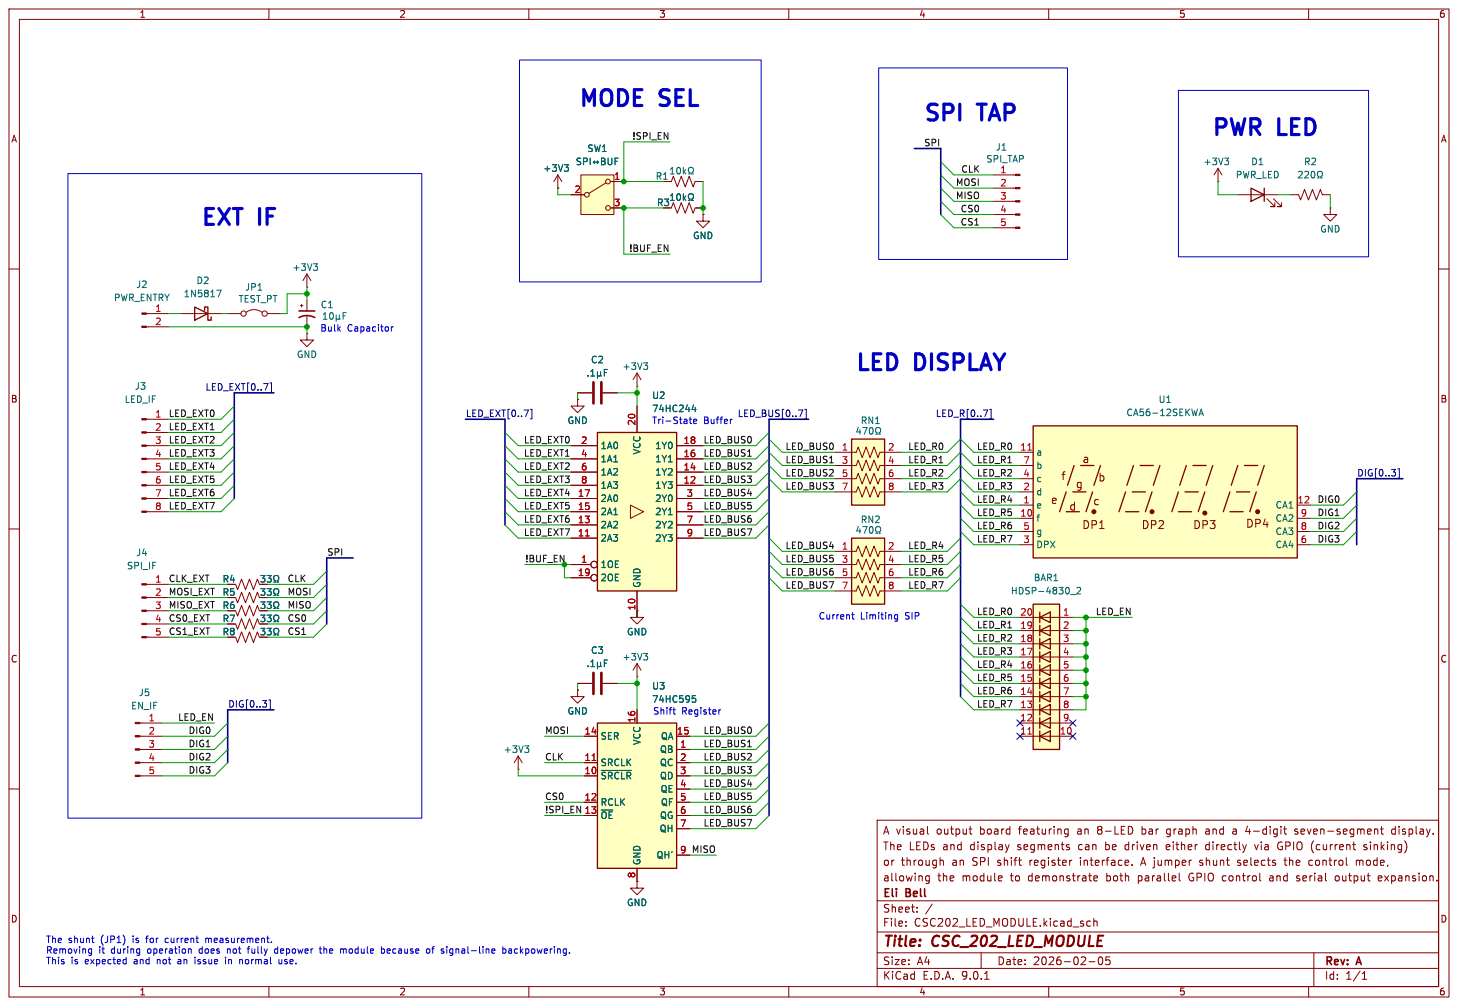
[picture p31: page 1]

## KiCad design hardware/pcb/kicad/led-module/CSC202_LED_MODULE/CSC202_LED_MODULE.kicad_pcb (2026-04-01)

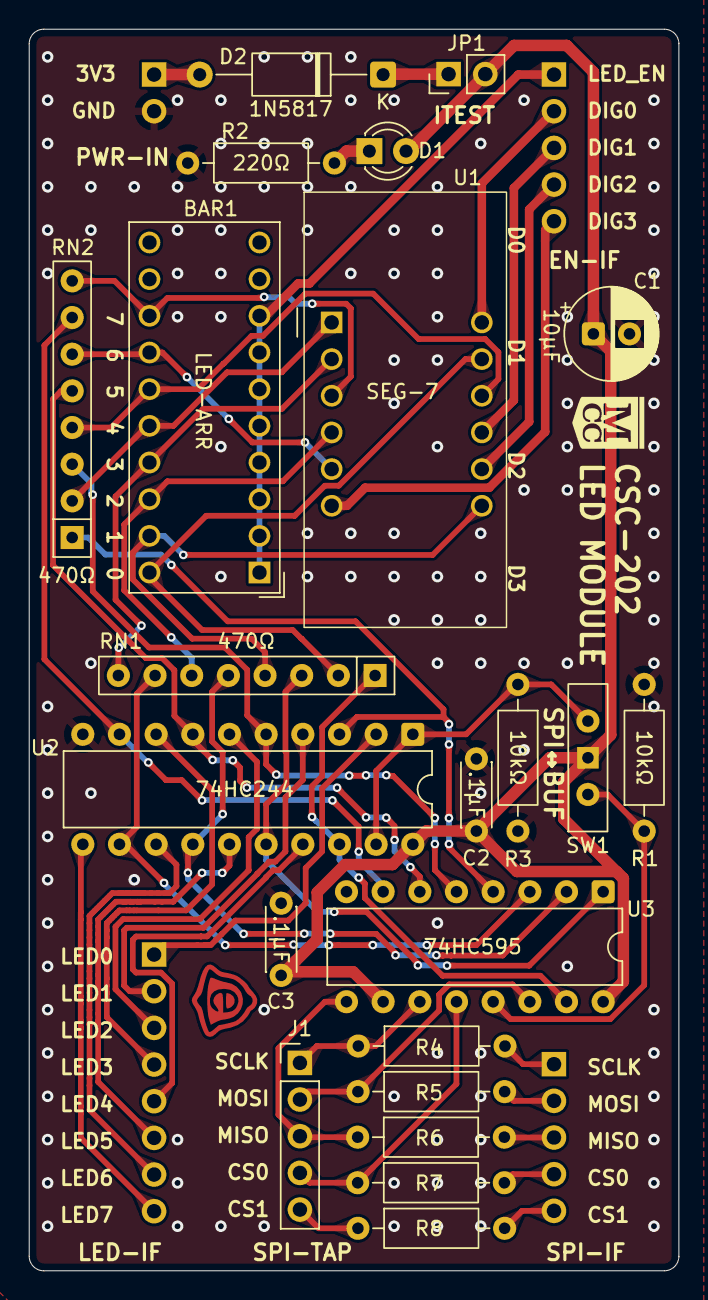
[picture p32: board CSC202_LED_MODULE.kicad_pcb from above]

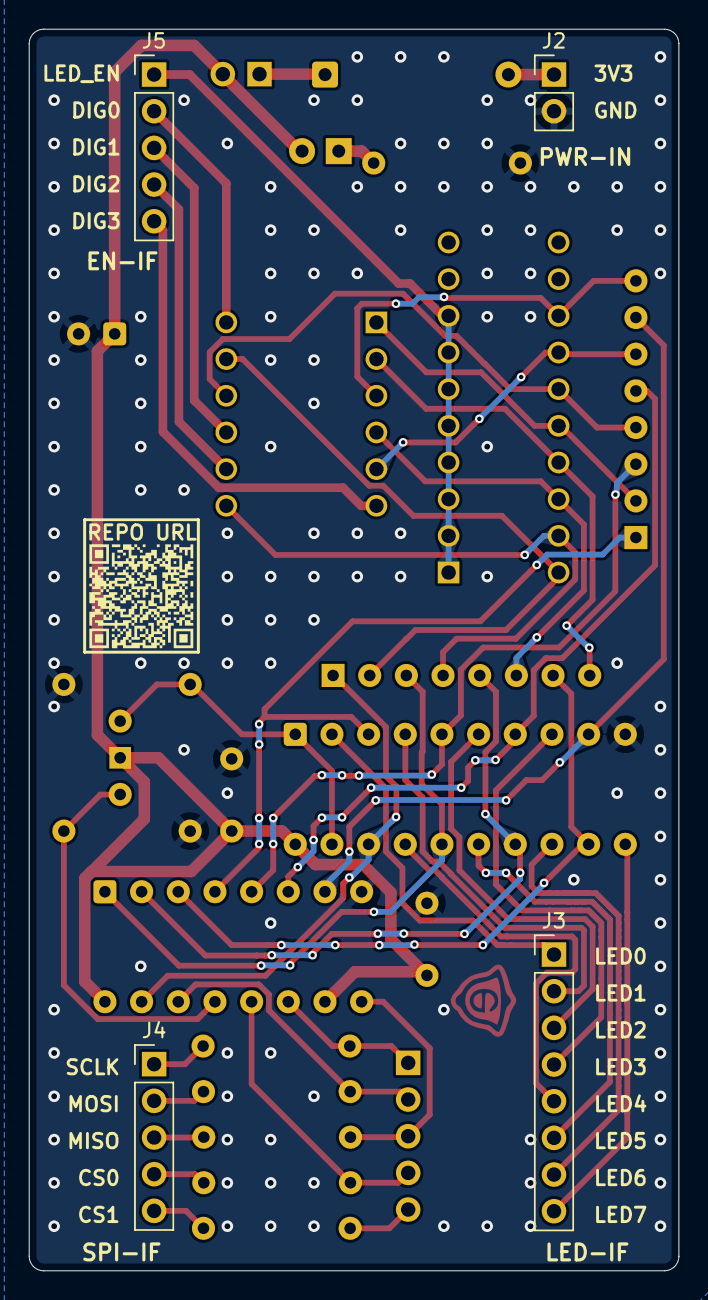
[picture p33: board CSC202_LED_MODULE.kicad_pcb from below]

Board: 2 copper layers, 45.0 x 86.0 mm, 26 parts (4 on the bottom side), 46 nets.

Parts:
BAR1: HDSP-4830_2; HDSP-4830
C1: 10µF; CP_Radial_D6.3mm_P2.50mm
C2, C3: .1µF; C_Disc_D4.3mm_W1.9mm_P5.00mm
D1: PWR; LED_D3.0mm
D2: 1N5817; D_A-405_P12.70mm_Horizontal
J1: SPI-TAP; PinHeader_1x05_P2.54mm_Vertical
J2: PWR-IN; PinHeader_1x02_P2.54mm_Vertical
J3: LED-IF; PinHeader_1x08_P2.54mm_Vertical
J4: SPI-IF; PinHeader_1x05_P2.54mm_Vertical
J5: EN-IF; PinHeader_1x05_P2.54mm_Vertical
JP1: TEST-PT; PinHeader_1x02_P2.54mm_Vertical
R1, R3: 10kΩ; R_Axial_DIN0207_L6.3mm_D2.5mm_P10.16mm_Horizontal
R2: 220Ω; R_Axial_DIN0207_L6.3mm_D2.5mm_P10.16mm_Horizontal
R4, R5, R6, R7, R8: 33Ω; R_Axial_DIN0207_L6.3mm_D2.5mm_P10.16mm_Horizontal
RN1, RN2: 470Ω; R_Array_SIP8
SW1: BUF↔SPI; SW_Slide-03_Wuerth-WS-SLTV_10x2.5x6.4_P2.54mm
U1: CA56-12SEKWA; CL3641BH
U2: 74HC244; DIP-20_W7.62mm
U3: 74HC595; DIP-16_W7.62mm

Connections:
+3V3: C1.1, C2.2, C3.2, D1.2 (A), JP1.2 (B), SW1.2 (B), U2.20 (VCC), U3.10 (~SRCLR), U3.16 (VCC)
/!BUF_EN: R3.1, SW1.3 (C), U2.1 (1OE), U2.19 (2OE)
/!SPI_EN: R1.1, SW1.1 (A), U3.13 (~OE)
/CLK: J1.1, R4.1, U3.11 (SRCLK)
/CLK_EXT: J4.1, R4.2
/CS0: J1.4, R7.1, U3.12 (RCLK)
/CS0_EXT: J4.4, R7.2
/CS1: J1.5, R8.1
/CS1_EXT: J4.5, R8.2
/DIG0: J5.2, U1.12 (CA1)
/DIG1: J5.3, U1.9 (CA2)
/DIG2: J5.4, U1.8 (CA3)
/DIG3: J5.5, U1.6 (CA4)
/LED_BUS0: RN1.1 (R1.1), U2.18 (1Y0), U3.15 (QA)
/LED_BUS1: RN1.3 (R2.1), U2.16 (1Y1), U3.1 (QB)
/LED_BUS2: RN1.5 (R3.1), U2.14 (1Y2), U3.2 (QC)
/LED_BUS3: RN1.7 (R4.1), U2.12 (1Y3), U3.3 (QD)
/LED_BUS4: RN2.1 (R1.1), U2.3 (2Y0), U3.4 (QE)
/LED_BUS5: RN2.3 (R2.1), U2.5 (2Y1), U3.5 (QF)
/LED_BUS6: RN2.5 (R3.1), U2.7 (2Y2), U3.6 (QG)
/LED_BUS7: RN2.7 (R4.1), U2.9 (2Y3), U3.7 (QH)
/LED_EN: BAR1.1 (A), BAR1.2 (A), BAR1.3 (A), BAR1.4 (A), BAR1.5 (A), BAR1.6 (A), BAR1.7 (A), BAR1.8 (A), J5.1
/LED_EXT0: J3.1, U2.2 (1A0)
/LED_EXT1: J3.2, U2.4 (1A1)
/LED_EXT2: J3.3, U2.6 (1A2)
/LED_EXT3: J3.4, U2.8 (1A3)
/LED_EXT4: J3.5, U2.17 (2A0)
/LED_EXT5: J3.6, U2.15 (2A1)
/LED_EXT6: J3.7, U2.13 (2A2)
/LED_EXT7: J3.8, U2.11 (2A3)
/LED_R0: BAR1.20 (K), RN1.2 (R1.2), U1.11 (a)
/LED_R1: BAR1.19 (K), RN1.4 (R2.2), U1.7 (b)
/LED_R2: BAR1.18 (K), RN1.6 (R3.2), U1.4 (c)
/LED_R3: BAR1.17 (K), RN1.8 (R4.2), U1.2 (d)
/LED_R4: BAR1.16 (K), RN2.2 (R1.2), U1.1 (e)
/LED_R5: BAR1.15 (K), RN2.4 (R2.2), U1.10 (f)
/LED_R6: BAR1.14 (K), RN2.6 (R3.2), U1.5 (g)
/LED_R7: BAR1.13 (K), RN2.8 (R4.2), U1.3 (DPX)
/MISO: J1.3, R6.1, U3.9 (QH')
/MISO_EXT: J4.3, R6.2
/MOSI: J1.2, R5.1, U3.14 (SER)
/MOSI_EXT: J4.2, R5.2
GND: C1.2, C2.1, C3.1, J2.2, R1.2, R2.1, R3.2, U2.10 (GND), U3.8 (GND)
unnamed: D1.1 (K), R2.2
unnamed: D2.2 (A), J2.1
unnamed: D2.1 (K), JP1.1 (A)

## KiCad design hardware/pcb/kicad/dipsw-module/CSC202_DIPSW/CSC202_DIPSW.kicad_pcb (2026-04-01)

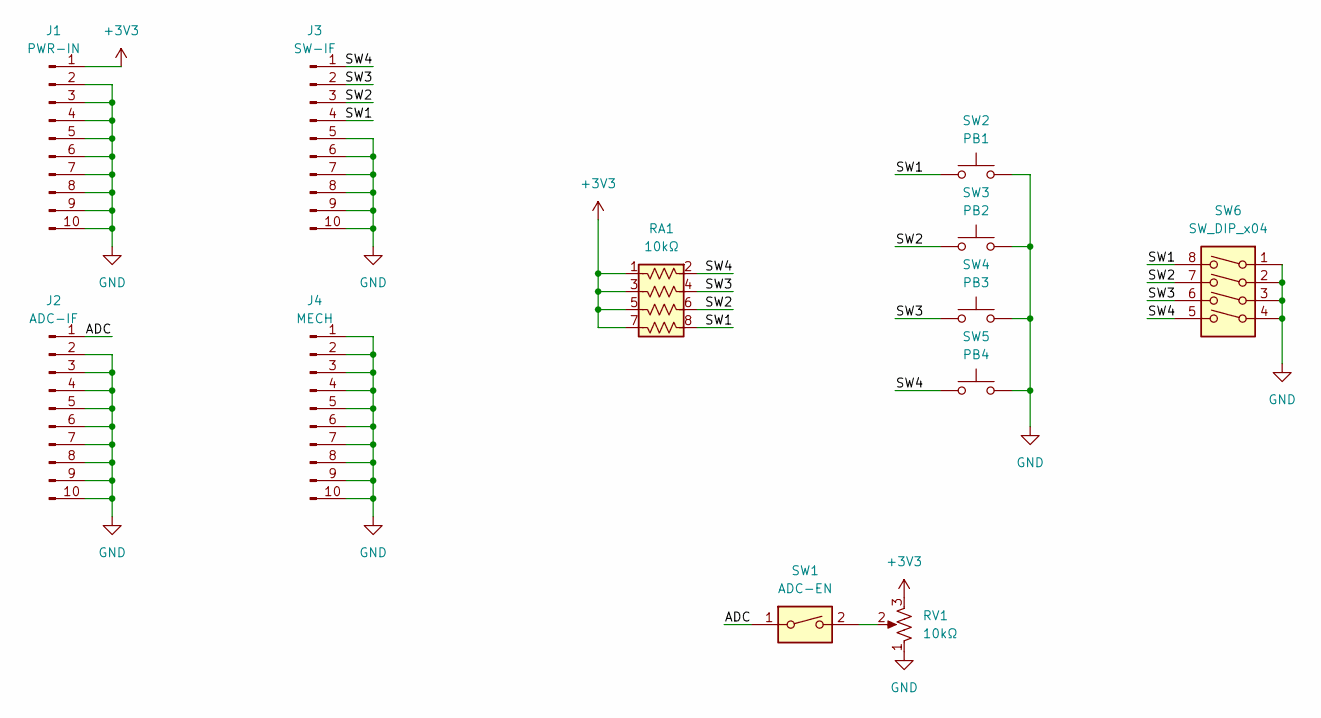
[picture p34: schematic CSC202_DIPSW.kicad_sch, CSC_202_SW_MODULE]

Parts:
J1: PWR-IN; PinHeader_1x10_P2.54mm_Vertical
J2: ADC-IF; PinHeader_1x10_P2.54mm_Vertical
J3: SW-IF; PinHeader_1x10_P2.54mm_Vertical
J4: MECH; PinHeader_1x10_P2.54mm_Vertical
RA1: 10kΩ; R_Array_SIP8
RV1: 10kΩ; Potentiometer_Piher_T-16H_Single_Horizontal
SW1: ADC-EN; SW_DIP_SPSTx01_Slide_9.78x4.72mm_W7.62mm_P2.54mm
SW2: PB1; SW_PUSH_6mm
SW3: PB2; SW_PUSH_6mm
SW4: PB3; SW_PUSH_6mm
SW5: PB4; SW_PUSH_6mm
SW6: SW_DIP_x04; SW_DIP_SPSTx04_Slide_9.78x12.34mm_W7.62mm_P2.54mm

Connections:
+3V3: J1.1, RA1.1 (R1a), RA1.3 (R2a), RA1.5 (R3a), RA1.7 (R4a), RV1.3 (1)
/ADC: J2.1, SW1.1
/SW1: J3.4, RA1.8 (R4b), SW2.2, SW6.8
/SW2: J3.3, RA1.6 (R3b), SW3.2, SW6.7
/SW3: J3.2, RA1.4 (R2b), SW4.2, SW6.6
/SW4: J3.1, RA1.2 (R1b), SW5.2, SW6.5
GND: J1.2, J1.3, J1.4, J1.5, J1.6, J1.7, J1.8, J1.9, J1.10, J2.2, J2.3, J2.4, J2.5, J2.6, J2.7, J2.8, J2.9, J2.10, J3.5, J3.6, J3.7, J3.8, J3.9, J3.10, J4.1, J4.2, J4.3, J4.4, J4.5, J4.6, J4.7, J4.8, J4.9, J4.10, RV1.1 (3), SW2.1, SW3.1, SW4.1, SW5.1, SW6.1, SW6.2, SW6.3, SW6.4
unnamed: RV1.2, SW1.2

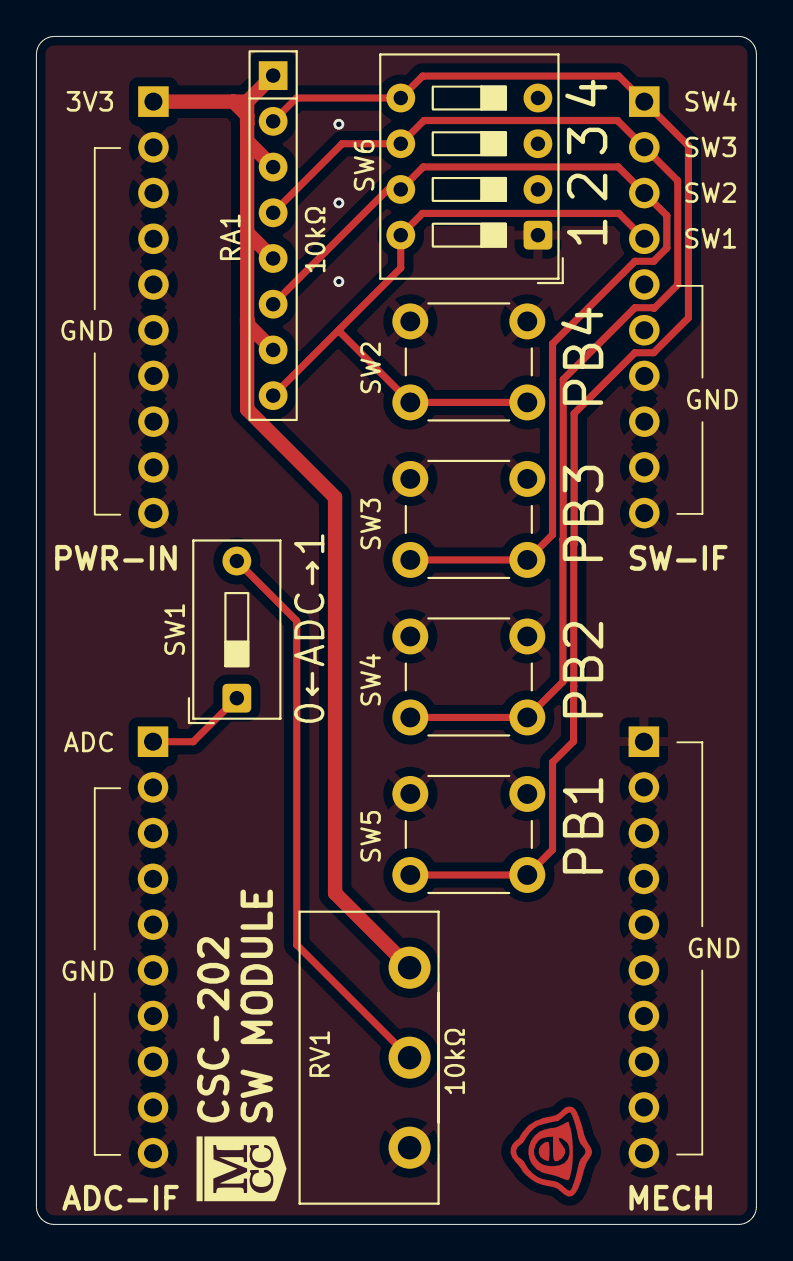
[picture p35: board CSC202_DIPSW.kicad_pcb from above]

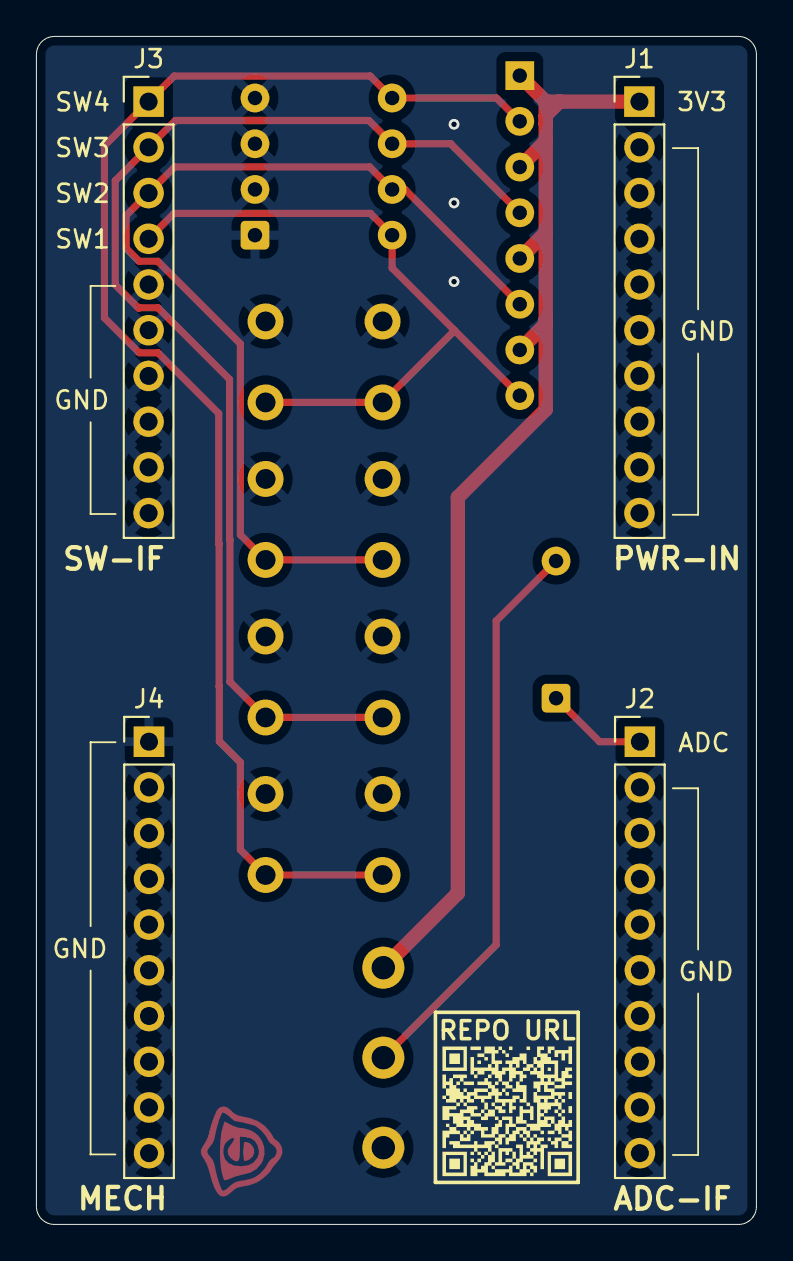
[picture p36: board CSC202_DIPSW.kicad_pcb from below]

Board: 2 copper layers, 40.0 x 66.0 mm, 12 parts (4 on the bottom side), 8 nets.

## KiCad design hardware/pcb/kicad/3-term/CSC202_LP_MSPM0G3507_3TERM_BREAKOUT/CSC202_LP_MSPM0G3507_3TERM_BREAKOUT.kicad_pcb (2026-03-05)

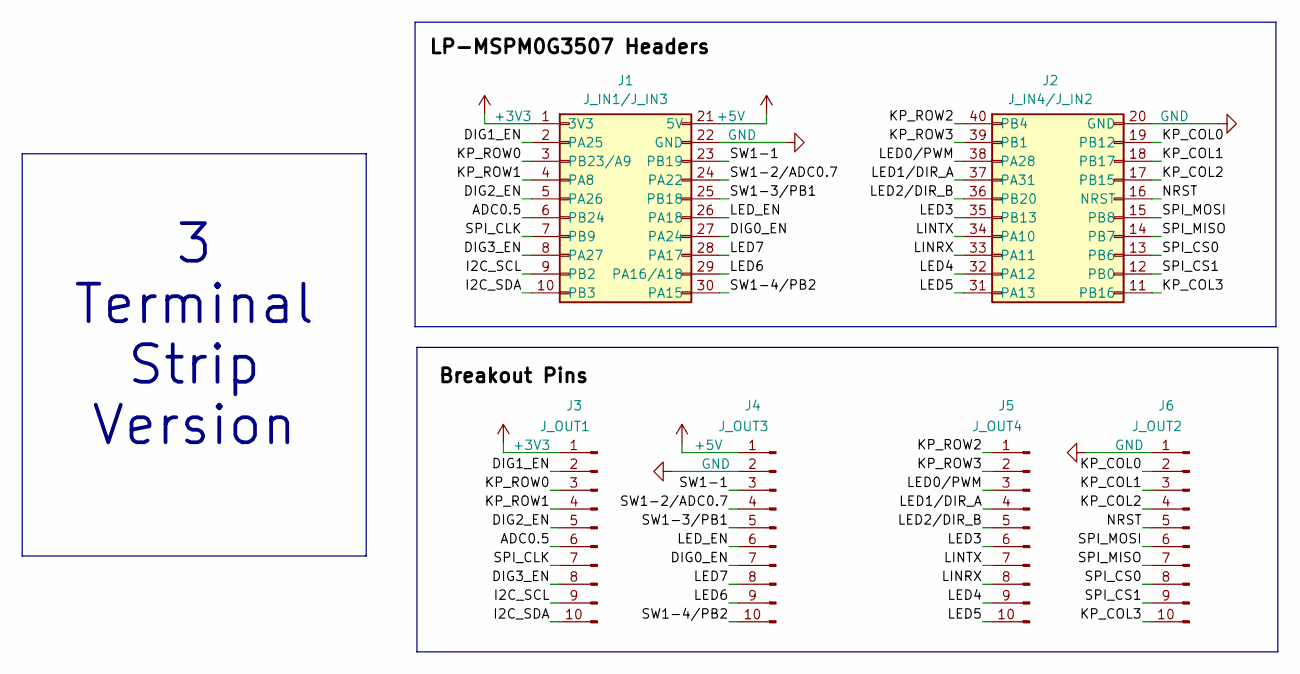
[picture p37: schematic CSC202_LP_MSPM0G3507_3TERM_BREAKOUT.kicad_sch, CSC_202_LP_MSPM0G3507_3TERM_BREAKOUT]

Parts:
J1: J_IN1/J_IN3; PinHeader_2x10_P2.54mm_Vertical
J2: J_IN4/J_IN2; PinHeader_2x10_P2.54mm_Vertical
J3: J_OUT1; PinHeader_1x10_P2.54mm_Vertical
J4: J_OUT3; PinHeader_1x10_P2.54mm_Vertical
J5: J_OUT4; PinHeader_1x10_P2.54mm_Vertical
J6: J_OUT2; PinHeader_1x10_P2.54mm_Vertical

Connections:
+3V3: J1.1 (3V3), J3.1
+5V: J1.21 (5V), J4.1
/ADC0.5: J1.6 (PB24), J3.6
/DIG0_EN: J1.27 (PA24), J4.7
/DIG1_EN: J1.2 (PA25), J3.2
/DIG2_EN: J1.5 (PA26), J3.5
/DIG3_EN: J1.8 (PA27), J3.8
/I2C_SCL: J1.9 (PB2), J3.9
/I2C_SDA: J1.10 (PB3), J3.10
/KP_COL0: J2.19 (PB12), J6.2
/KP_COL1: J2.18 (PB17), J6.3
/KP_COL2: J2.17 (PB15), J6.4
/KP_COL3: J2.11 (PB16), J6.10
/KP_ROW0: J1.3 (PB23/A9), J3.3
/KP_ROW1: J1.4 (PA8), J3.4
/KP_ROW2: J2.40 (PB4), J5.1
/KP_ROW3: J2.39 (PB1), J5.2
/LED0/PWM: J2.38 (PA28), J5.3
/LED1/DIR_A: J2.37 (PA31), J5.4
/LED2/DIR_B: J2.36 (PB20), J5.5
/LED3: J2.35 (PB13), J5.6
/LED4: J2.32 (PA12), J5.9
/LED5: J2.31 (PA13), J5.10
/LED6: J1.29 (PA16/A18), J4.9
/LED7: J1.28 (PA17), J4.8
/LED_EN: J1.26 (PA18), J4.6
/LINRX: J2.33 (PA11), J5.8
/LINTX: J2.34 (PA10), J5.7
/NRST: J2.16 (NRST), J6.5
/SPI_CLK: J1.7 (PB9), J3.7
/SPI_CS0: J2.13 (PB6), J6.8
/SPI_CS1: J2.12 (PB0), J6.9
/SPI_MISO: J2.14 (PB7), J6.7
/SPI_MOSI: J2.15 (PB8), J6.6
/SW1-1: J1.23 (PB19), J4.3
/SW1-2/ADC0.7: J1.24 (PA22), J4.4
/SW1-3/PB1: J1.25 (PB18), J4.5
/SW1-4/PB2: J1.30 (PA15), J4.10
GND: J1.22 (GND), J2.20 (GND), J4.2, J6.1

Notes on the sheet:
3 Terminal Strip Version

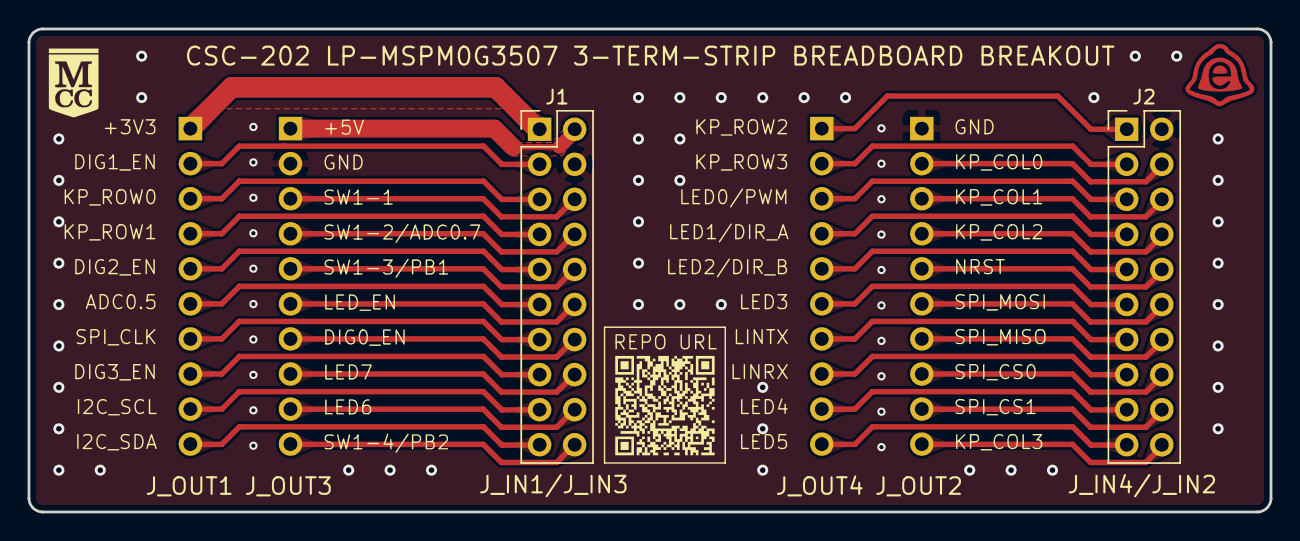
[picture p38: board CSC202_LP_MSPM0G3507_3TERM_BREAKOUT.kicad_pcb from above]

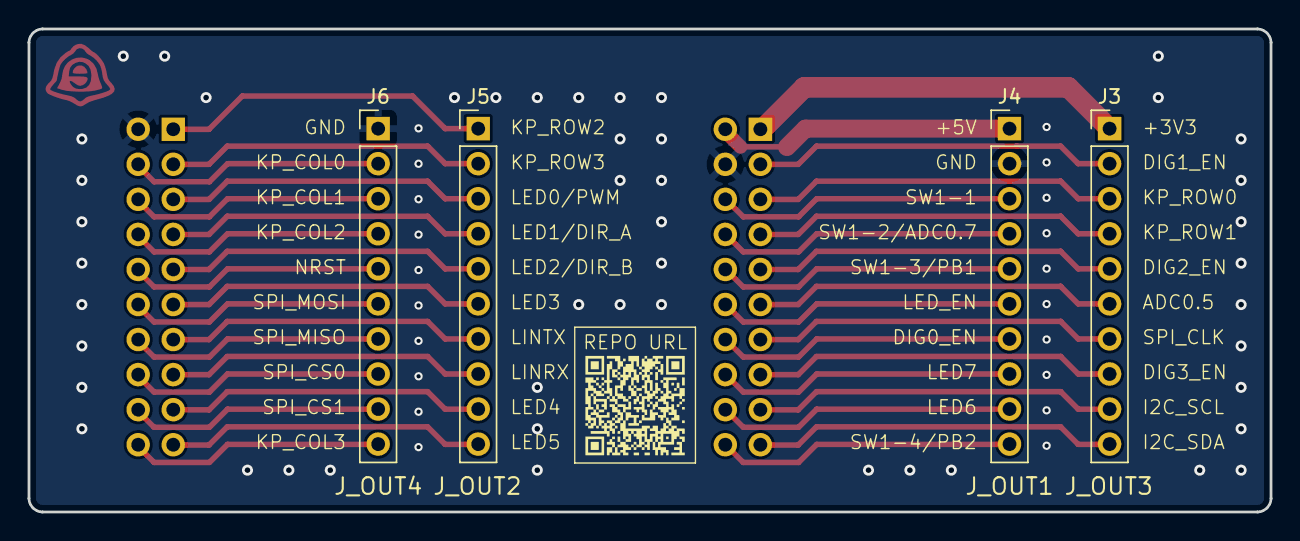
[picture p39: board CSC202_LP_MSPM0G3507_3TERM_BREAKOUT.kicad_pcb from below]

Board: 2 copper layers, 90.0 x 35.0 mm, 9 parts (5 on the bottom side), 39 nets.

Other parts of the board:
G1, G2: LOGO; Repo_URL_QR
LOGO1: LOGO; MCC-Logo

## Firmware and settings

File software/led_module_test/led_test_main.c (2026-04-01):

//*****************************************************************************
//*****************************    C Source Code    ****************************
//*****************************************************************************
//  DESIGNER NAME:  Eli Bell
//
//       PROJECT:  CSC202 Expansion Board Test Program
//
//      FILE NAME:  led_test_main.c
//
//-----------------------------------------------------------------------------
//
// DESCRIPTION:
//    This program runs on the LP_MSPM0G3507 LaunchPad and interfaces with a
//    custom CSC202 Expansion PCB.
//
//    The expansion board contains:
//      - An 8-channel LED bar
//      - A 4-digit 7-segment hexadecimal display
//
//    Both peripherals can be controlled through two selectable hardware modes:
//      1. SPI Mode:
//         Data is shifted into an external shift register via SPI and latched
//         using a chip select (CS) signal.
//      2. GPIO Mode:
//         Data is driven directly over an 8-bit parallel bus through a
//         non-inverting buffer.
//
//    A physical switch on the PCB selects between SPI and GPIO control paths.
//    This software updates BOTH paths regardless of switch position so that
//    either mode is immediately functional when toggled.
//
//    The program performs a "walking bit" test pattern:
//      - A single '1' bit shifts left across all outputs
//      - Then shifts back right
//      - Repeats for both LED bar and 7-segment display
//
//    For the 7-segment display:
//      - Each loop iteration updates a different digit index
//      - This demonstrates multiplexing across all digits
//
//    This test verifies:
//      - SPI communication and latch timing
//      - GPIO parallel output functionality
//      - Buffer and shift register hardware correctness
//      - LED and 7-segment display operation
//
//*****************************************************************************
//*****************************************************************************

//-----------------------------------------------------------------------------
// Loads standard C include files
//-----------------------------------------------------------------------------
#include <stdio.h>

//-----------------------------------------------------------------------------
// Loads MSP launchpad board support macros and definitions
//-----------------------------------------------------------------------------
#include "LaunchPad.h"
#include "clock.h"
#include "spi.h"
#include <ti/devices/msp/msp.h>

//-----------------------------------------------------------------------------
// Define symbolic constants used by the program
//-----------------------------------------------------------------------------

#define BAUD_RATE (115200) // UART debug (unused here)

#define SPI_CONFIG_DELAY (50) // Delay for SPI latch timing (ms)

#define WALK_TEST_REPEAT_COUNT (4) // Number of sweep repetitions

#define ON_TIME (100) // Delay between pattern updates (ms)

//-----------------------------------------------------------------------------
// Define global variables and structures here.
// NOTE: when possible avoid using global variables
//-----------------------------------------------------------------------------

// Mode selection for which peripheral to actively drive via GPIO
typedef enum
{
    LEDS, // Drive LED bar via GPIO
    SEG7, // Drive 7-segment display via GPIO
} Mode;

//-----------------------------------------------------------------------------
// Define function prototypes used by the program
//-----------------------------------------------------------------------------

void walk_test(Mode mode);
void update(uint8_t data, Mode mode, uint8_t seg7_idx);

//-----------------------------------------------------------------------------
// Main Function
//-----------------------------------------------------------------------------
int main(void)
{
    // System initialization
    clock_init_40mhz();
    launchpad_gpio_init();

    // Peripheral initialization
    leds_init();
    leds_disable(); // Start with LEDs off
    seg7_init();
    spi1_init();

    // Configure SPI Chip Select (CS) as GPIO for manual control
    IOMUX->SECCFG.PINCM[LP_SPI_CS0_IOMUX] =
        IOMUX_PINCM_PC_CONNECTED | PINCM_GPIO_PIN_FUNC;
    GPIOB->DOE31_0 |= LP_SPI_CS0_MASK;   // Set as output
    GPIOB->DOUT31_0 &= ~LP_SPI_CS0_MASK; // Initialize low

    // Main loop: continuously test both modes
    while (1)
    {
        walk_test(LEDS);
        walk_test(SEG7);
    }
}

//-----------------------------------------------------------------------------
// walk_test
//
// DESCRIPTION:
//    Performs a walking-bit test pattern on the selected output mode.
//
//    The pattern:
//      - Shifts a single '1' bit from LSB → MSB
//      - Then shifts back MSB → LSB
//
//    For SEG7 mode:
//      - Cycles through digit indices to demonstrate multiplexing
//
// PARAMETERS:
//    mode - LEDS or SEG7
//-----------------------------------------------------------------------------
void walk_test(Mode mode)
{
    uint8_t data;
    uint8_t seg7_idx;

    // Enable/disable LED buffer depending on mode
    switch (mode)
    {
    case LEDS:
        leds_enable(); // Enable LED GPIO path
        break;

    case SEG7:
        leds_disable(); // Prevent LED contention
        break;
    }

    for (uint8_t loop_count = 0; loop_count < WALK_TEST_REPEAT_COUNT;
         loop_count++)
    {
        // Cycle through 7-segment digits
        seg7_idx = loop_count % MAX_NUM_SEG7_DISPLAYS;

        data = 1;

        // Shift left across outputs
        uint8_t led_idx = 0;
        for (; led_idx < MAX_NUM_LEDS - 1; led_idx++)
        {
            update(data, mode, seg7_idx);
            data = data << 1;
        }

        // Shift right back across outputs
        for (led_idx = MAX_NUM_LEDS; led_idx > 1; led_idx--)
        {
            update(data, mode, seg7_idx);
            data = data >> 1;
        }
    }

    // Turn off outputs at end of test
    data = 1;
    update(data, mode, seg7_idx);
    update(--data, mode, seg7_idx); // clears output
}

//-----------------------------------------------------------------------------
// update
//
// DESCRIPTION:
//    Updates both SPI and GPIO output paths with the given data.
//
//    Operation:
//      1. Disable 7-segment display to avoid ghosting
//      2. Send inverted data over SPI to shift register
//      3. Toggle chip select (CS) to latch data
//      4. Drive selected output via GPIO (LED or 7-seg)
//      5. Wait for visible persistence
//
// PARAMETERS:
//    data      - 8-bit pattern to display
//    mode      - LEDS or SEG7
//    seg7_idx  - Active 7-segment digit index
//-----------------------------------------------------------------------------
void update(uint8_t data, Mode mode, uint8_t seg7_idx)
{
    uint8_t recv = 0;

    // Turn off display before updating (prevents ghosting)
    seg7_off();

    // Send data to shift register (SPI path)
    spi1_write_data(~data);  // Inverted due to hardware wiring
    recv = spi1_read_data(); // Dummy read (optional/debug)

    // Latch SPI data using CS pulse
    GPIOB->DOUT31_0 |= LP_SPI_CS0_MASK;
    msec_delay(SPI_CONFIG_DELAY);
    GPIOB->DOUT31_0 &= ~LP_SPI_CS0_MASK;

    // Drive GPIO path based on selected mode
    switch (mode)
    {
    case LEDS:
        leds_on(data);
        break;

    case SEG7:
        seg7_on(data, seg7_idx);
        break;
    }

    // Hold output for visibility
    msec_delay(ON_TIME);
}

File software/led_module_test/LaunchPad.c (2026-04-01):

// *****************************************************************************
// ***************************    C Source Code     ****************************
// *****************************************************************************
//    DESIGNER NAME:  Bruce Link
//
//         VERSION:  1.0
//
//        FILE NAME:  LaunchPad.c
//
//-----------------------------------------------------------------------------
// DESCRIPTION
//     This file contains a collection of functions for initializing and
//     configuring various hardware peripherals on the LP-MSPM0G3507 LaunchPad
//     and the CSC202 Expansion Board, including:
//       - LED control
//       - 7-segment display management
//       - 4x4 matrix keypad interfacing
//       - DIP switch reading
//       - I2C communication management
//       - PWM Motor Management
//       - DAC Management
//       - OPA Management
//
//     This code is adapted from various Texas Instruments' LaunchPad
//     project template for the LP-MSPM0G3507, using C language and no RTOS.
//
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
//    The author and organization do not warrant the accuracy, completeness, or
//    reliability of the code. The author and organization shall not be liable
//    for any direct, indirect, incidental, special, exemplary, or consequential
//    damages arising out of the use of or inability to use the code, even if
//    advised of the possibility of such damages.
//
//    Use of this code is at your own risk, and it is recommended to validate
//    and adapt the code for your specific application and hardware 
//    requirements.
//
// Copyright (c) 2024 by Bruce Link
//    You may use, edit, run or distribute this file as long as the above
//    copyright notice remains
// *****************************************************************************
//******************************************************************************

//-----------------------------------------------------------------------------
// Load standard C include files
//-----------------------------------------------------------------------------
#include <stdint.h>
#include <stdio.h>

//-----------------------------------------------------------------------------
// Loads MSP launchpad board support macros and definitions
//-----------------------------------------------------------------------------
#include <ti/devices/msp/msp.h>
#include <ti/devices/msp/peripherals/hw_iomux.h>
#include "LaunchPad.h"
#include "clock.h"


//-----------------------------------------------------------------------------
// Define symbolic constants used by program
//-----------------------------------------------------------------------------
#define PERIPHERAL_PWR_UP_DELAY                                            (24)
#define ACTIVE_LOW                                                          (0)
#define ACTIVE_HIGH                                                         (1)


//-----------------------------------------------------------------------------
// Define global variable and structures here.
// NOTE: when possible avoid using global variables
//-----------------------------------------------------------------------------

// Define a structure to hold led configuration data
typedef struct
{
  uint8_t  port_id;
  uint32_t bit_mask;
  uint16_t pin_cm;
  uint8_t  polarity;
} gpio_struct;

// // Define a structure to hold led configuration data
typedef struct
{
  uint8_t  port_id;
  uint32_t bit_mask;
  uint16_t pin_cm;
  uint8_t  io_func;
} i2c_struct;


// Define the configuration data for the LEDs on the LP-MSPM0G3507
const gpio_struct lp_led_config_data[] = {
        {LP_LED_RED_PORT, LP_LED_RED_MASK, LP_LED_RED_IOMUX, ACTIVE_LOW},
        {LP_RGB_RED_PORT, LP_RGB_RED_MASK, LP_RGB_RED_IOMUX, ACTIVE_HIGH},
        {LP_RGB_GRN_PORT, LP_RGB_GRN_MASK, LP_RGB_GRN_IOMUX, ACTIVE_HIGH},
        {LP_RGB_BLU_PORT, LP_RGB_BLU_MASK, LP_RGB_BLU_IOMUX, ACTIVE_HIGH}
};

// Define the configuration data for the LEDs on the CSC202 Board
const gpio_struct led_config_data[] = {
        {LED0_PORT, LED0_MASK, LED0_IOMUX, ACTIVE_LOW},
        {LED1_PORT, LED1_MASK, LED1_IOMUX, ACTIVE_LOW},
        {LED2_PORT, LED2_MASK, LED2_IOMUX, ACTIVE_LOW},
        {LED3_PORT, LED3_MASK, LED3_IOMUX, ACTIVE_LOW},
        {LED4_PORT, LED4_MASK, LED4_IOMUX, ACTIVE_LOW},
        {LED5_PORT, LED5_MASK, LED5_IOMUX, ACTIVE_LOW},
        {LED6_PORT, LED6_MASK, LED6_IOMUX, ACTIVE_LOW},
        {LED7_PORT, LED7_MASK, LED7_IOMUX, ACTIVE_LOW}
};

// Define the configuration data for the enables on the CSC202 Board
const gpio_struct enable_controls[] = {
        {ENABLE_DIG0_PORT, ENABLE_DIG0_MASK, ENABLE_DIG0_IOMUX, ACTIVE_HIGH},
        {ENABLE_DIG1_PORT, ENABLE_DIG1_MASK, ENABLE_DIG1_IOMUX, ACTIVE_HIGH},
        {ENABLE_DIG2_PORT, ENABLE_DIG2_MASK, ENABLE_DIG2_IOMUX, ACTIVE_HIGH},
        {ENABLE_DIG3_PORT, ENABLE_DIG3_MASK, ENABLE_DIG3_IOMUX, ACTIVE_HIGH},
        {ENABLE_LED_PORT,  ENABLE_LED_MASK,  ENABLE_LED_IOMUX, ACTIVE_HIGH}
};

// Define the configuration data for the switches on the LaunchPad Board
const gpio_struct lp_switch_config_data[] = {
        {LP_SW1_PORT, LP_SW1_MASK, LP_SW1_IOMUX, ACTIVE_HIGH},
        {LP_SW2_PORT, LP_SW2_MASK, LP_SW2_IOMUX, ACTIVE_LOW}
};

// Define the configuration data for the switches on the CSC202 Board
const gpio_struct dip_switch_config_data[] = {
        {DIP_SW1_PORT, DIP_SW1_MASK, DIP_SW1_IOMUX, ACTIVE_LOW},
        {DIP_SW2_PORT, DIP_SW2_MASK, DIP_SW2_IOMUX, ACTIVE_LOW},
        {DIP_SW3_PORT, DIP_SW3_MASK, DIP_SW3_IOMUX, ACTIVE_LOW},
        {DIP_SW4_PORT, DIP_SW4_MASK, DIP_SW4_IOMUX, ACTIVE_LOW}
};

// Define the configuration data for the 4x4 Keypad on the CSC202 Board
const gpio_struct kp_col_config_data[] = {
        {KP_COL0_PORT, KP_COL0_MASK, KP_COL0_IOMUX, ACTIVE_HIGH},
        {KP_COL1_PORT, KP_COL1_MASK, KP_COL1_IOMUX, ACTIVE_HIGH},
        {KP_COL2_PORT, KP_COL2_MASK, KP_COL2_IOMUX, ACTIVE_HIGH},
        {KP_COL3_PORT, KP_COL3_MASK, KP_COL3_IOMUX, ACTIVE_HIGH}
};

// Define the configuration data for the 4x4 Keypad on the CSC202 Board
const gpio_struct kp_row_config_data[] = {
        {KP_ROW0_PORT, KP_ROW0_MASK, KP_ROW0_IOMUX, ACTIVE_HIGH},
        {KP_ROW1_PORT, KP_ROW1_MASK, KP_ROW1_IOMUX, ACTIVE_HIGH},
        {KP_ROW2_PORT, KP_ROW2_MASK, KP_ROW2_IOMUX, ACTIVE_HIGH},
        {KP_ROW3_PORT, KP_ROW3_MASK, KP_ROW3_IOMUX, ACTIVE_HIGH}
};

// Define the configuration data for the IIC port on the CSC202 Board
const i2c_struct iic_config_data[] = {
        {I2C_SDA_PORT, I2C_SDA_MASK, I2C_SDA_IOMUX, I2C_SDA_PINCM_IOMUX_FUNC},
        {I2C_SCL_PORT, I2C_SCL_MASK, I2C_SCL_IOMUX, I2C_SCL_PINCM_IOMUX_FUNC}
};
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

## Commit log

2025-09-23 3-term complete
    [CSC202_LP_MSPM0G3507_3TERM_BREAKOUT-B_Cu.gbl, CSC202_LP_MSPM0G3507_3TERM_BREAKOUT-B_Mask.gbs, CSC202_LP_MSPM0G3507_3TERM_BREAKOUT-B_Paste.gbp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]
2025-09-30 completed 2-term version
    [CSC202_LP_MSPM0G3507_2TERM_BREAKOUT-B_Cu.gbl, CSC202_LP_MSPM0G3507_2TERM_BREAKOUT-B_Mask.gbs, CSC202_LP_MSPM0G3507_2TERM_BREAKOUT-B_Paste.gbp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]
2025-10-21 board fabricated
2026-01-15 Restructure repo for KiBot + MkDocs workflow
    [CSC202_LP_MSPM0G3507_2TERM_BREAKOUT-B_Cu.gbl, CSC202_LP_MSPM0G3507_2TERM_BREAKOUT-B_Mask.gbs, CSC202_LP_MSPM0G3507_2TERM_BREAKOUT-B_Paste.gbp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]
2026-01-16 implemented kibot and mkdocs
    [CSC202_LP_MSPM0G3507_2TERM_BREAKOUT-3D.step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]
2026-01-16 Revise README with detailed project information
    Updated README to include hardware documentation, board details, and repo layout.
2026-03-05 init led module
    [CSC202_LED_MODULE-3D.step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]
2026-03-05 Add LED Display Module section to README
    Added section for the LED Display Module with details and links.
2026-03-05 added side-by-side front/bottom renders to mkdocs homepage for the led module board
    [CSC202_LED_MODULE-3D.step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]
2026-03-05 Enhance LED Module description with prototyping details
    Added details about breadboard compatibility for easy prototyping.
2026-03-06 added reverse polarity protection and included bottom assy in outputs
    [CSC202_LED_MODULE-3D.step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]
2026-03-06 fixed broken link issue in index.md
    [CSC202_LED_MODULE-3D.step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]
2026-03-07 restore repository contents
    [CSC202_LED_MODULE-3D.step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]
2026-04-01 add DIP switch + pushbutton module (pcb, docs, outputs)
    [CSC202_DIPSW-3D.step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]
2026-04-01 add switch module 3D render
2026-04-01 add MSPM0 LED module test project
2026-04-01 add DIP switch module KiCad design
    [CSC202_DIPSW.kicad_pcb, CSC202_DIPSW.kicad_sch]
2026-04-01 add DIP switch module generated artifacts and docs page
    [CSC202_DIPSW-3D.step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]
2026-04-01 update LED module KiCad design
    [CSC202_LED_MODULE.kicad_pcb, CSC202_LED_MODULE.kicad_sch]
2026-04-01 regenerate LED module artifacts
    [CSC202_LED_MODULE-3D.step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]
2026-04-01 regenerate 2-term and 3-term breakout artifacts
    [CSC202_LP_MSPM0G3507_2TERM_BREAKOUT-3D.step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]
2026-04-01 Add DIP Switch / Pushbutton Module section to README
    Added details about the DIP Switch / Pushbutton Module, including its features and links to documentation and downloads.
2026-04-01 add fabricated led module photo
2026-04-01 replace fabricated led module photo
2026-04-01 Revise fabricated board photo section
    Updated section title and added photo of LED Display Module.
2026-04-07 note added to sch concerning backpowering
    [CSC202_LED_MODULE.kicad_sch]
2026-04-07 update outputs
    [CSC202_DIPSW-3D.step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]
